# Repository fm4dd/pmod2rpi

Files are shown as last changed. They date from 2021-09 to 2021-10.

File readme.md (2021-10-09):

## PMOD2RPI

### Description

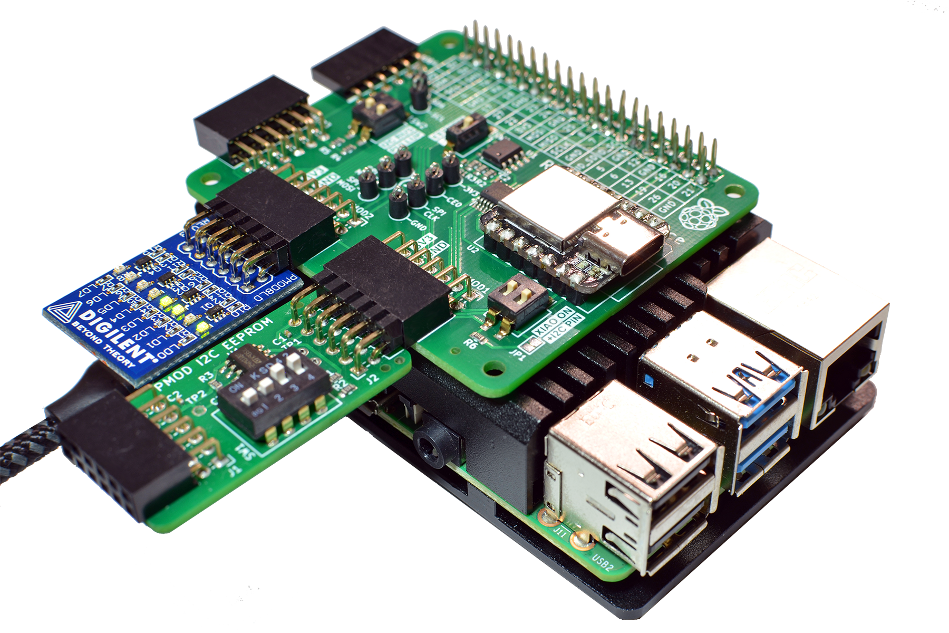
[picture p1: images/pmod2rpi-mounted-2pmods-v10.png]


PMOD2RPI is a PMOD-compatible Interface Board for the Raspberry Pi B-type GPIO connector. It provides a total of four PMOD connectors to run PMOD-compatible modules on the Raspberry Pi.  This board is compatible to PMOD interface standard v1.3.1 by Digilent Inc. The PMOD (peripheral module interface) standard enables simple plug-in connectivity between FPGA or microcontroller development boards, and a range of input/output modules.

This design is registered under the OSHWA Open Source Hardware Self-Certification:  


 While all connectors provide digital IO, they also double as serial bus connectors for I2C and SPI modules. To aid troubleshooting, a set of Keystone miniature testpins can be fitted to create access for oscilloscope and DMM monitoring. A Seeeduino XIAO footprint has been added to additionally drive two of the four PMOD's, or to communicate with the RPi. The XIAO is optional, and can operate with the board "standalone" if needed.

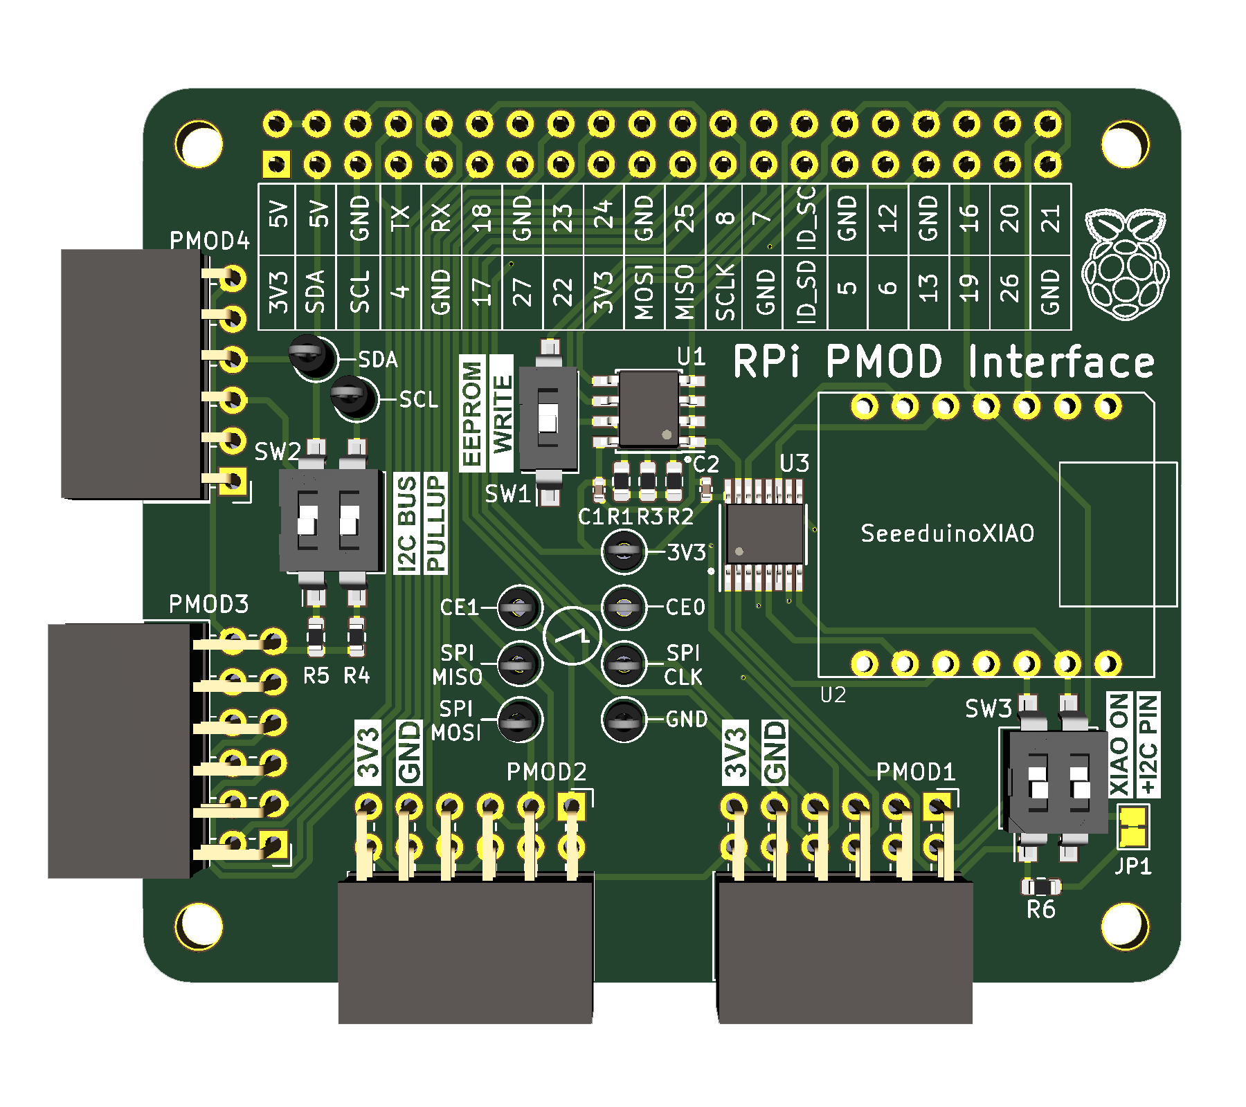
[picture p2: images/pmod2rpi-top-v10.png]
 

#### I2C /SPI signal switching on PMOD1

The PMOD interface standard v1.3.1 added a new extended I2C connector type 6A, which runs the I2C bus signals over the same pins 3/4 that are already used for SPI. In order to allow both bus types to be used on a single connector, switch SW3 allows to swap the I2C signals between pins 3/4 and 9/10 on PMOD1.

See also http://fpga.fm4dd.com/

### Schematic

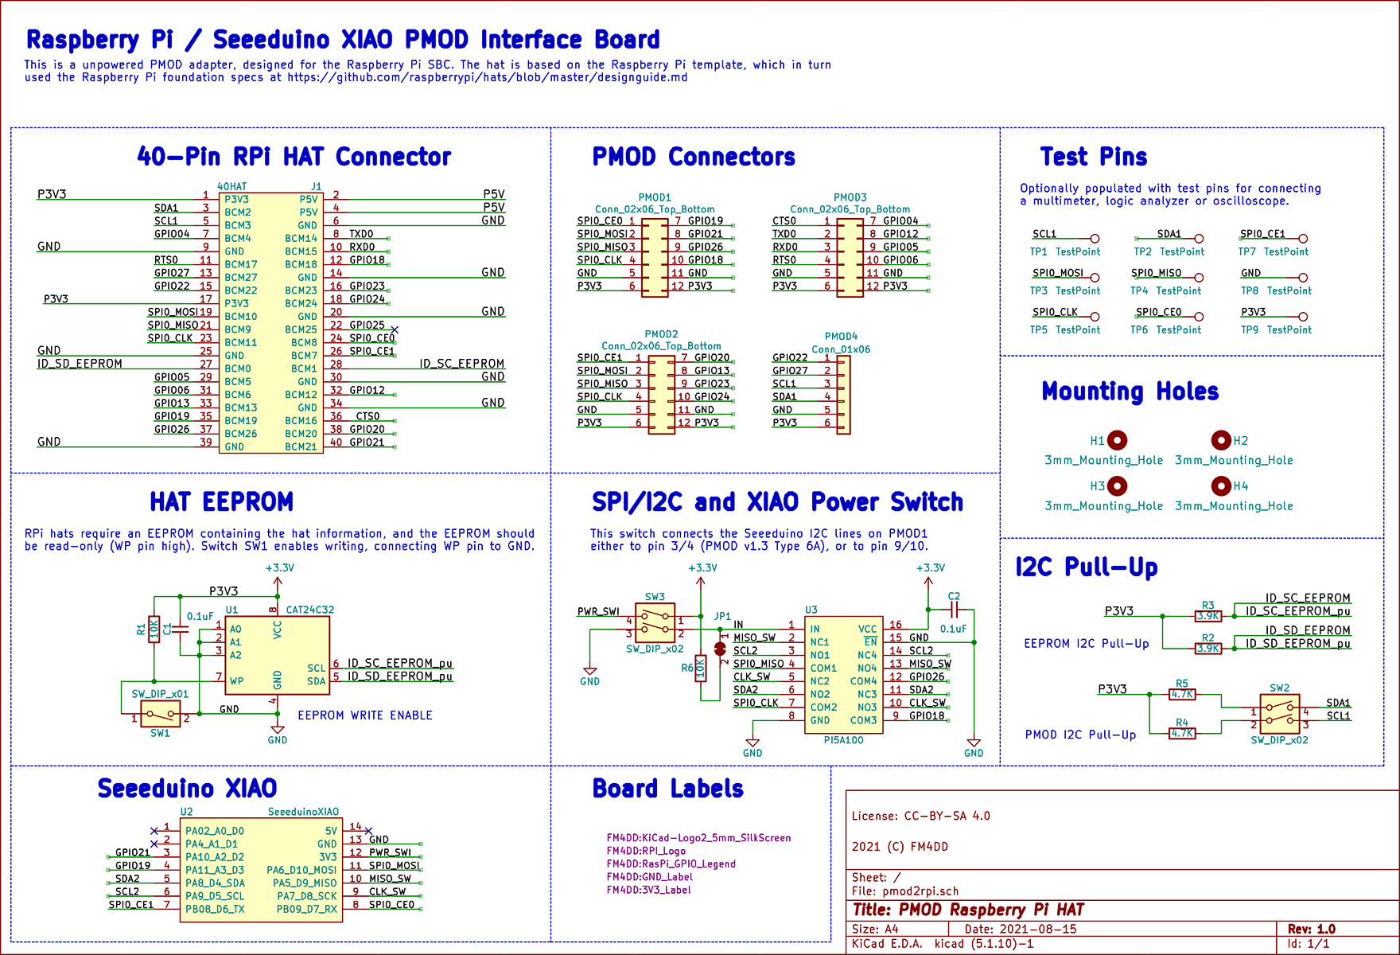
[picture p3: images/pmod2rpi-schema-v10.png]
I2C24IO PMOD Schematics


### Hardware Versions

| Version | Gerber | Schema |
|---|---|---|
| 1.0 |[20210821-pmod2rpi-gerber-v10.zip](release/v10/20210821-pmod2rpi-gerber-v10.zip) | [20210821-pmod2rpi-schema-v10.pdf](release/v10/20210821-pmod2rpi-schema-v10.pdf) |

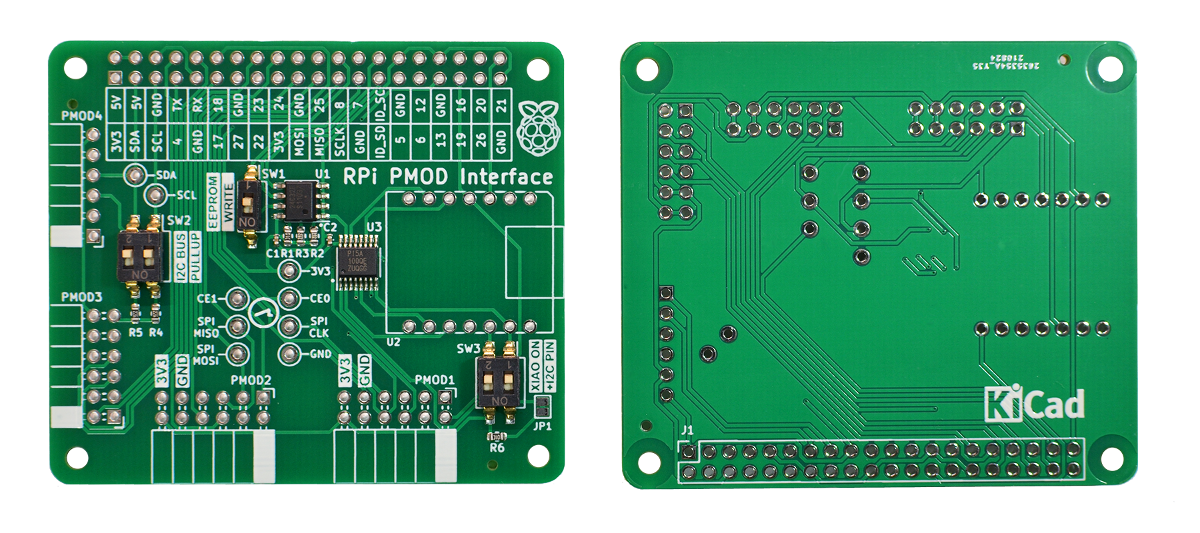
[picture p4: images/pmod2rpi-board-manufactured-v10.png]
 

### Pin Assignments

Pin assigments are listed in the separate [pmod2rpi-pinout.md](pmod2rpi-pinout.md) file.
Below are simplified schematics for the XIAO MCU-specific connectivity.

#### XIAO - PMOD1:

A multi-purpose double-row connector that can used as GPIO Type-1 and Type-1A, SPI Type-2 and Type-2A, or I2C Type-6 or Type-6A, depending on the pin configuration of the XIAO.
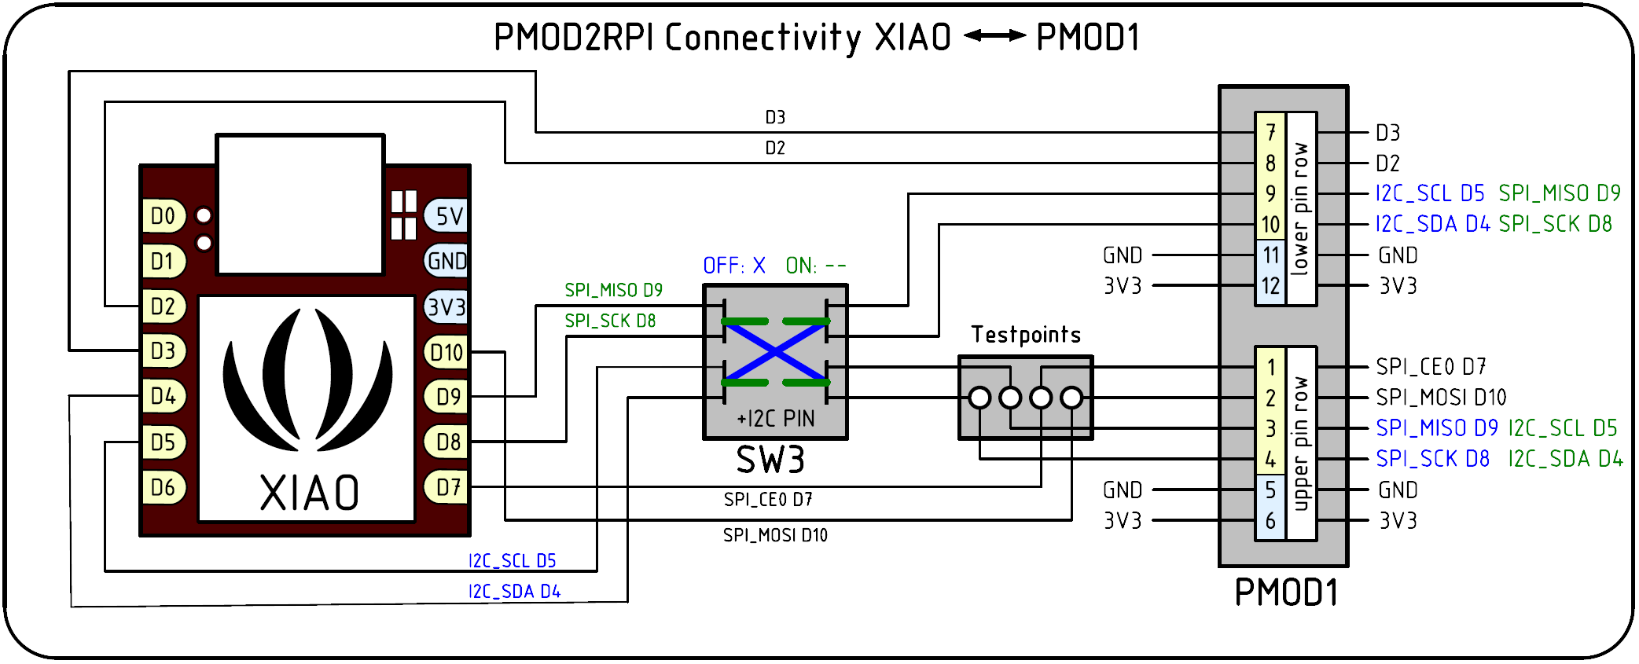
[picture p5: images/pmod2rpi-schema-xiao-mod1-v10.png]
I2C24IO PMOD Schematics

#### XIAO - PMOD2:

A double-row connector that can use only the upper row for GPIO Type-1, SPI Type-2, or I2C Type-6 configurations. The lower pins are connected to the Raspberry Pi only.
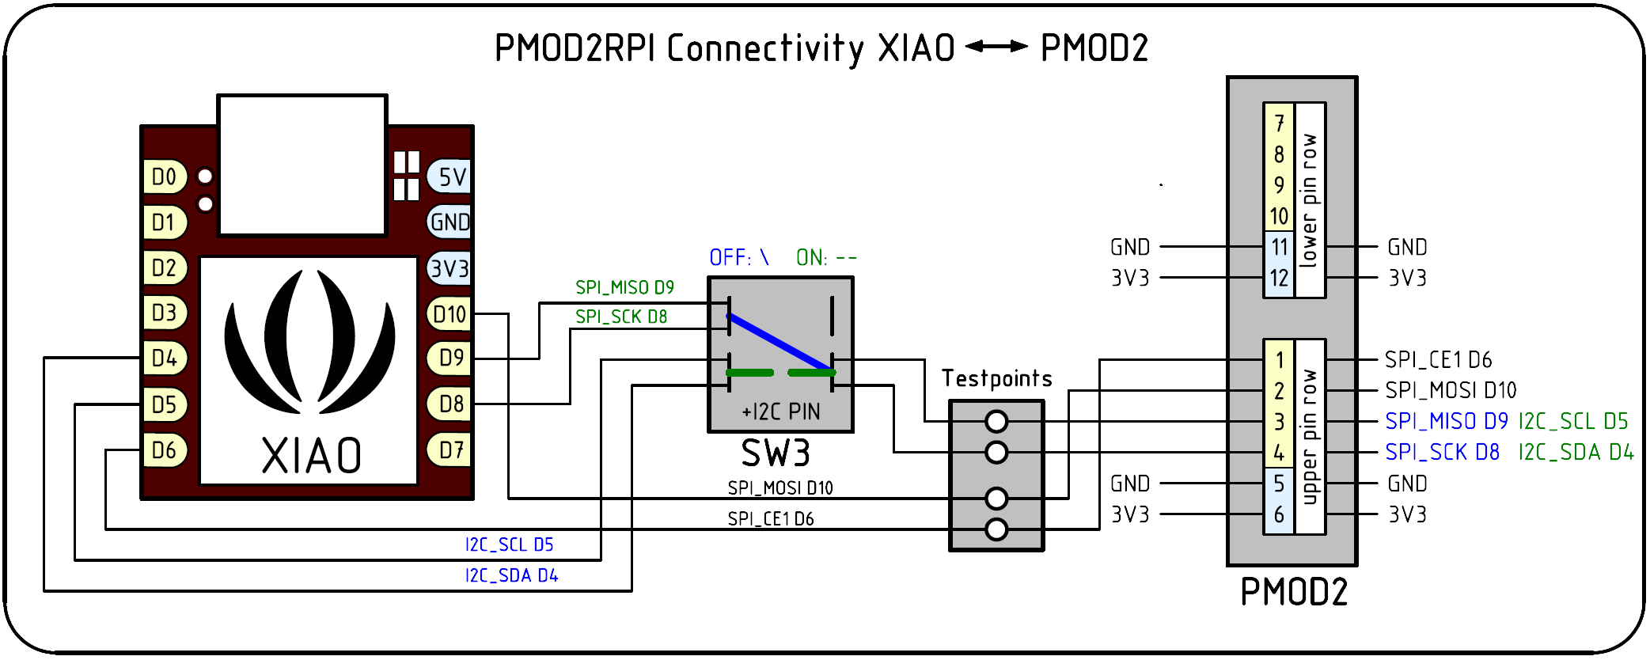
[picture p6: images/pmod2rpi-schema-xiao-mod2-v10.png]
I2C24IO PMOD Schematics

#### XIAO - Raspberry Pi:

A set of XIAO pins are shared with the Raspberry Pi that can be used to establish GPIO and SPI connections. With bitbanging, I2C is also possible for data exchange between the Pi and the XIAO.
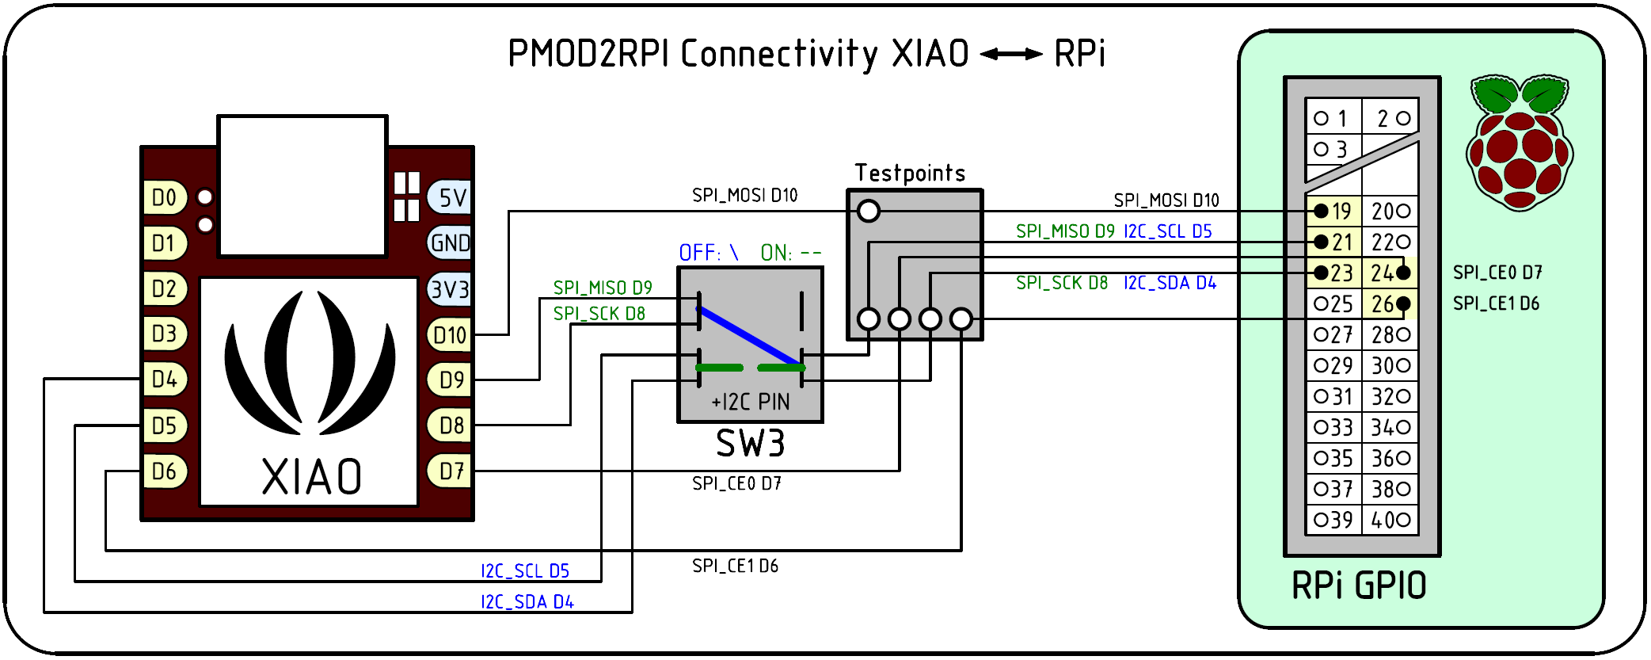
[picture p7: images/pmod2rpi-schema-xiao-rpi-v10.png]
I2C24IO PMOD Schematics


### Example Code

| Platform | Folder | Description |
|---|---|---|
|Raspberry Pi |[pi-gpiotest](examples/pi-gpiotest) | simple GPIO test program for digital IO PMODs, such as Digilent's PMOD8LD |
|Raspberry Pi |[pi-tca6424a](https://github.com/fm4dd/pmod-i2c24io/tree/master/examples/pi-tca6424a) | I2C module driver 'C' program to control the I2C expander module PMOD-I2C24IO connected to PMOD4 |
|Arduino |[xiao-digital-io](examples/xiao-digital-io) | Tests digital IO using the Digilent 8-Led PMOD 8LD connected to PMOD1 |
|Arduino |[xiao-pmod1-24iodemo](https://github.com/fm4dd/pmod-i2c24io/tree/master/examples/xiao-pmod1-24iodemo) | Creates a lightshow demo by rotating binary patterns over the 24 IO pins, lighting up connected LEDs |

I2C24IO PMOD demos are stored within the PMOD's repo located at [https://github.com/fm4dd/pmod-i2c24io](https://github.com/fm4dd/pmod-i2c24io).

### Board Pictures
I2C24IO PMOD connected to the RPi PMOD Interface board connector PMOD1, running the "xiao-pmod1-i2c24io" example program on the Seeeduino XIAO (Cortex M0) in "standalone" mode:
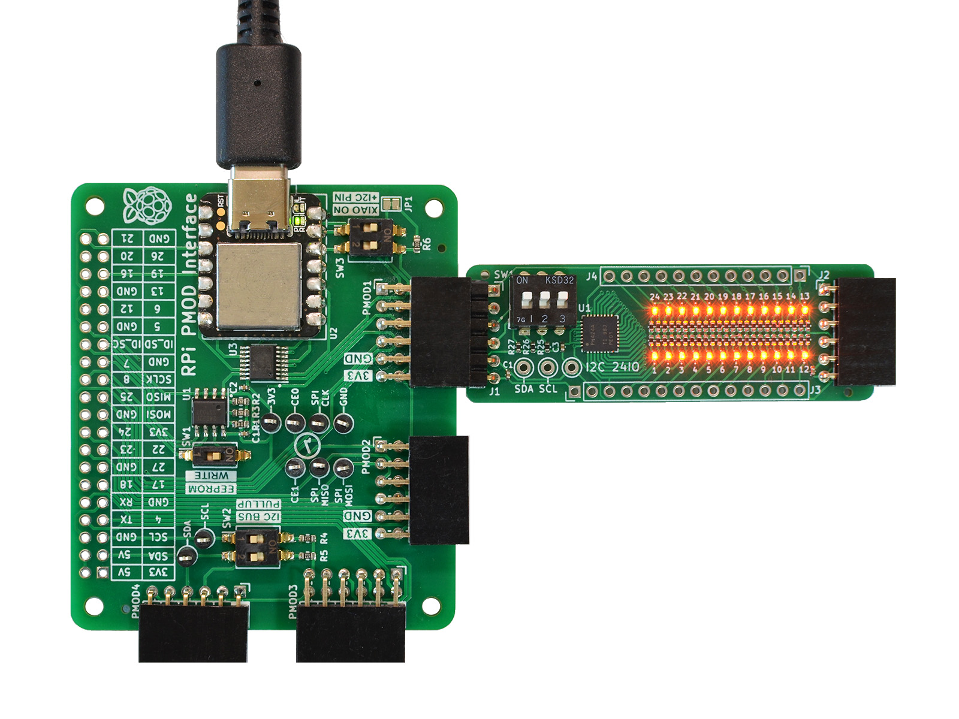
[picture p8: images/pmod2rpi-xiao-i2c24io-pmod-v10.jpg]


Raspberry Pi I2C signal measurements on the PMOD2RPI board:
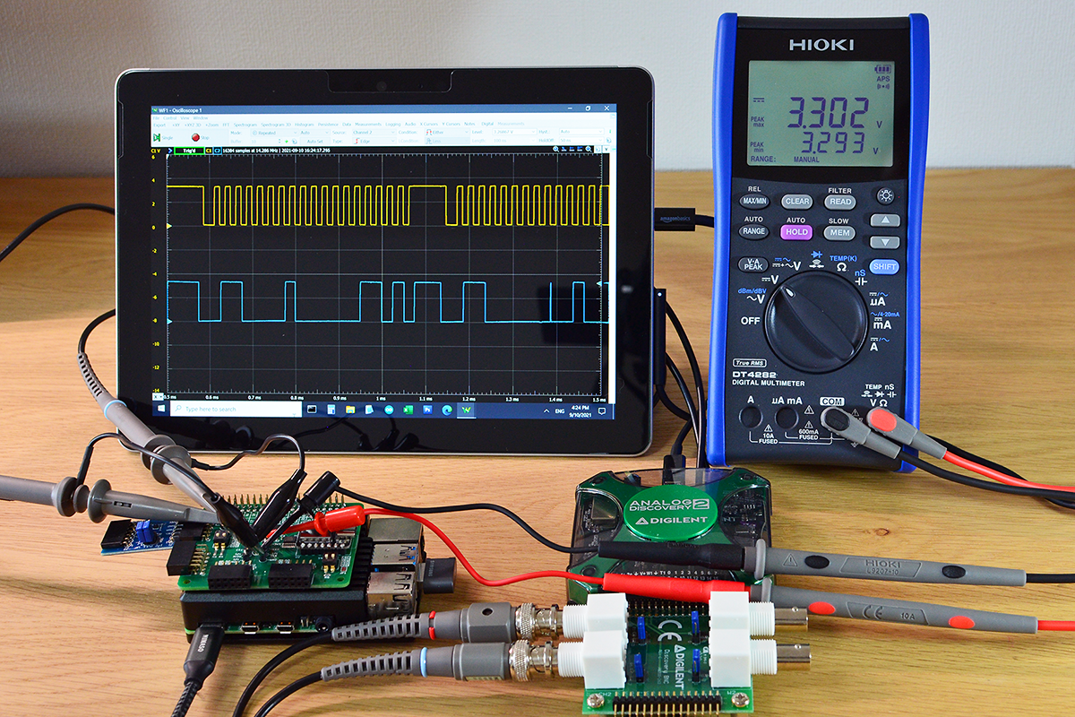
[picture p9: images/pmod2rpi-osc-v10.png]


Raspberry Pi operating the I2C24IO-PMOD module connected to PMOD4 on the PMOD2RPI board:
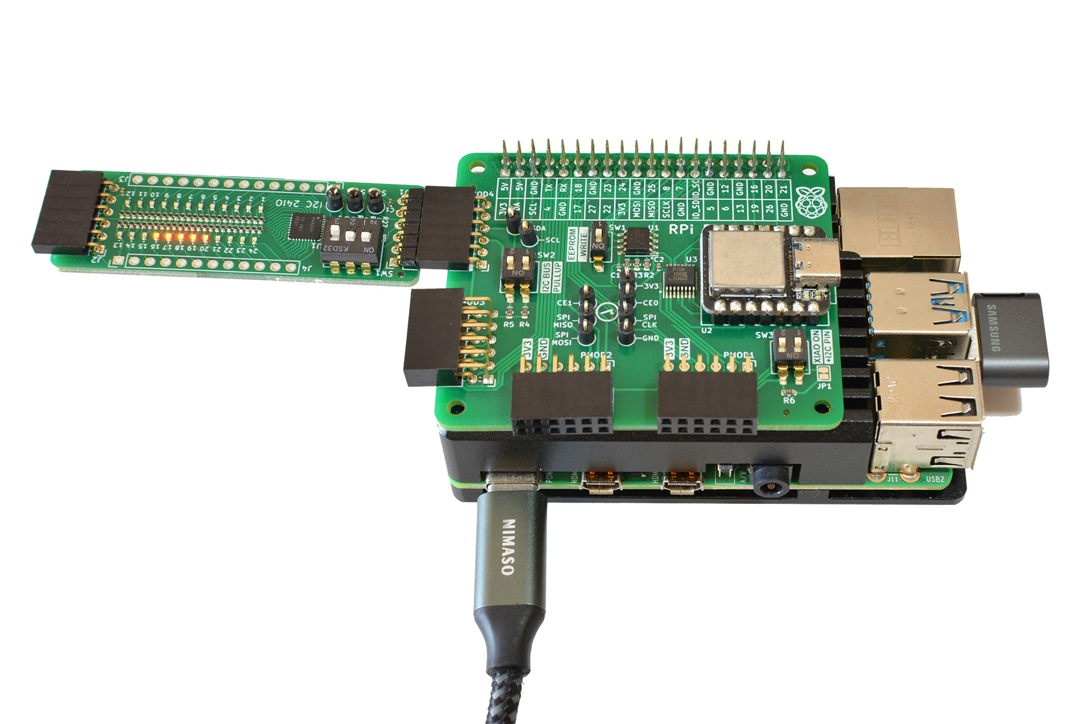
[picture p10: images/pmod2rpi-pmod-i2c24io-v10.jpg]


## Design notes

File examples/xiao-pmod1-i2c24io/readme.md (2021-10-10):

## XIAO-PMOD1-I2C24IO

Arduino Sketch for designs based on the I2C 24-bit digital expander IC Texas Instruments TCA6424A.
Implemented and tested on a PMOD2RPI interface board with a Seeeduino XIAO (Cortex M0+) and a I2C24IO PMOD module. 

### Usage

Running the sketch will output the following to the serial monitor:

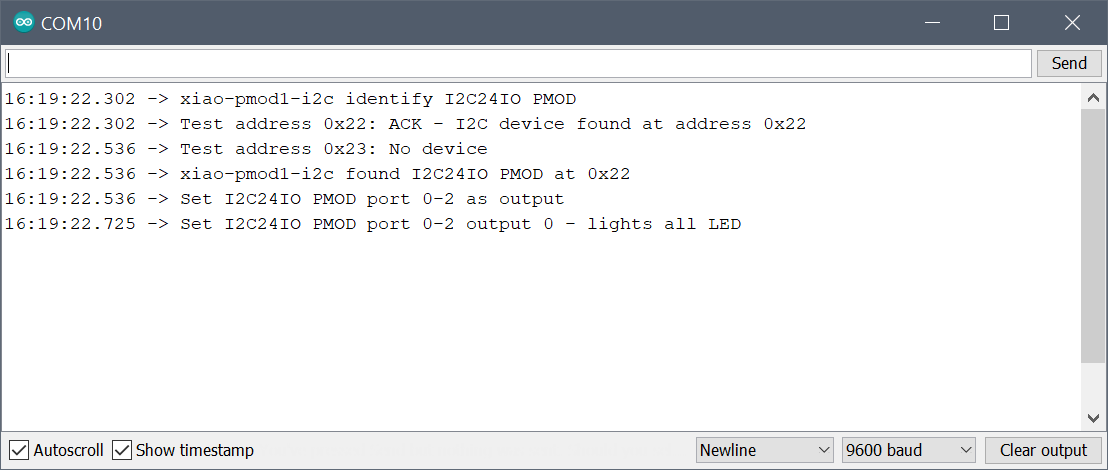
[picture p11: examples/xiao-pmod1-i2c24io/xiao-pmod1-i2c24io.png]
Sketch output to serial monitor


PMOD2RPI interface board with a Seeeduino XIAO (Cortex M0+) and a I2C24IO PMOD module:



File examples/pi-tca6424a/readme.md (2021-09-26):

## Pi-TCA6424A

Linux 'C' Control Code for designs based on the I2C 24-bit digital expander IC Texas Instruments TCA6424A.
Implemented and tested on a Raspberry Pi, using the PMOD2RPI interface board and a I2C24IO PMOD module. 

### Prerequisites

```
pi@pi-ms05:~ $ sudo apt install libi2c-dev libgpiod-dev
```

### Compilation

```
pi@pi-ms05:~/pmod-i2c24io/examples/pi-tca6424a $ make
gcc -O3 -Wall -g   -c -o i2c_tca6424a.o i2c_tca6424a.c
gcc -O3 -Wall -g   -c -o settca6424a.o settca6424a.c
gcc i2c_tca6424a.o settca6424a.o -o settca6424a -lgpiod
gcc -O3 -Wall -g   -c -o demotca6424a.o demotca6424a.c
gcc i2c_tca6424a.o demotca6424a.o -o demotca6424a -lgpiod
```

### Usage
```
pi@pi-ms05:~/pmod-i2c24io/examples/pi-tca6424a $ ./settca6424a
Usage: settca6424a [-b i2c-bus] [-d] [-i] -o [<24-bit output>, or all=0/1] [-r] [-v]

Command line parameters have the following format:
   -b   I2C bus to query, Example: -b /dev/i2c-1 (default)
   -d   dump the complete sensor register map content
   -i   print sensor information
   -o   24-bit binary output string, or all=0/1 to set all pins at once
        -o 111111110000000011111111 24 x 0/1 sets individual pins
        -o all=1 sets all pins 'on', -o all=0 sets all pins 'off'
   -r   reset sensor
   -h   display this message
   -v   enable debug output

Usage examples:
./settca6424a -b /dev/i2c-0 -i
./settca6424a -o all=1
./settca6424a -o 010101010101010101010101
```

### Examples

Enable all pins as output, and set the output level as '0':
```
pi@pi-ms05:~/pmod-i2c24io/examples/pi-tca6424a $ ./settca6424a -o all=0
```
Enable all pins as output, and set the output level as '1':
```
pi@pi-ms05:~/pmod-i2c24io/examples/pi-tca6424a $ ./settca6424a -o all=1
```
Enable all pins as output, and set individual pins according to the 24-bit pattern '111111110000000010101010':
```
pi@pi-ms05:~/pmod-i2c24io/examples/pi-tca6424a $ ./settca6424a -o 111111110000000010101010 -v
Debug: ts=[1632130627] date=Mon Sep 20 18:37:07 2021
Debug: Get pin gpio22: [direction 2]
Debug: Get pin gpio22: [act_state 1]
Debug: Set pin gpio22: [output '1']
Debug: I2C bus device: [/dev/i2c-1]
Debug: Sensor address: [0x22]
Debug: Got data @addr: [0x22]
Debug: Setting all ports as output complete
Debug: port0 data str: [11111111] hex [0xFF]
Debug: port1 data str: [00000000] hex [0x00]
Debug: port2 data str: [10101010] hex [0xAA]
Debug: Setting pin output as [111111110000000010101010] complete
```
Small one-liner to set pins as output, and alternate the pins output level:
``` 
pi@pi-ms05:~/pmod-i2c24io/examples/pi-tca6424a $ while true; do ./settca6424a -o 101010101010101010101010; \
> sleep 0.5; ./settca6424a -o 010101010101010101010101; sleep 0.5; done
```
Set a specific pin value, and dump the TCA6424A register values:
```
pi@pi-ms05:~/pmod-i2c24io/examples/pi-tca6424a $ ./settca6424a -o 111111110000000010101010
pi@pi-ms05:~/pmod-i2c24io/examples/pi-tca6424a $ ./settca6424a -d
------------------------------------------------------
Texas Instruments TCA6424A register dump:
------------------------------------------------------
 reg    0  1  2  3  4  5  6  7  8  9  A  B  C  D  E  F
------------------------------------------------------
[0x00] FF 00 AA -- FF 00 AA -- 00 00 00 -- 00 00 00 --
```

### Demo

```
pi@pi-ms05:~/pmod-i2c24io/examples/pi-tca6424a $ ./demotca6424a
```

demotca6424 is demonstration program for designs based on the I2C 24-bit digital expander IC Texas Instruments TCA6424A.
Implemented and tested on a Raspberry Pi 4 with a PMOD2RPI interface board, having the I2C24IO PMOD module on the PMOD4 connector.

### Usage

```
pi@pi-ms05:~/pmod-i2c24io/examples/pi-tca6424a $ ./demotca6424a -h
Usage: demotca6424a [-a addr] [-b i2c-bus] [-v]

Command line parameters have the following format:
   -a   module I2C bus address in hex, Example: -a 0x22 (default)
   -b   I2C bus to query, Example: -b /dev/i2c-1 (default)
   -h   display this message
   -v   enable debug output

Usage examples:
./demotca6424a -a 0x23 -b /dev/i2c-0
./demotca6424a -v
```

Running the sketch will output various LED patterns that indicate the IO signal status:

1. ON/OFF for all pins on the module
2. Moving a single bit through each of the 24 pins
3. Moving 3 bits, one for each of the 3 output ports
4. Increment pins from 0 until all port pins are ON/OFF
5. Moving 6 bits, two for each of the 3 output ports
6. Alternate the level for neighporing pins ON/OFF

This program executes in a permanent loop, terminate the program with 'CTL-C'.

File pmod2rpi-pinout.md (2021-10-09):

## RPi Pin Assignments

### Raspberry Pi 40-Pin Connector GPIO assignment list

| RPi Pin-# | RPi Pin Name | PMOD#-Pin# | RPi Pin-# | RPi Pin Name | PMOD#-Pin# |
|---|---|---|---|---|---|
| 1 | 3V3 | All (Pin-6) | 2 | 5V | - |
| 3 | GPIO02 | PMOD4-4 | 4 | 5V | - |
| 5 | GPIO03 | PMOD4-3 | 6 | GND | All (GND Pin-5)|
| 7 | GPIO04 | PMOD3-7 | 8 | GPIO14 | PMOD2-1 |
| 9 | GND | All (GND Pin-5) | 10 | GPIO15 | PMOD3-3 |
| 11 | GPIO17 | PMOD3-4 | 12 | GPIO18 | PMOD1-10 |
| 13 | GPIO27 | PMOD4-2 | 14 | GND | All (GND Pin-5)|
| 15 | GPIO22 | PMOD4-1 | 16 | GPIO23 | PMOD2-9 |
| 17 | 3V3 | All (Pin-6) | 18 | GPIO24 | PMOD2-10 |
| 19 | GPIO10 | PMOD1-2, PMOD2-2| 20 | GND | All (GND Pin-5)|
| 21 | GPIO09 | PMOD1-3, PMOD2-3| 22 | GPIO25 | PMOD2-10 |
| 23 | GPIO11 | PMOD1-4, PMOD2-4| 24 | GPIO08 | PMOD1-1 |
| 25 | GND | All (GND Pin-5) | 26 | GPIO07 | PMOD2-1 |
| 27 | ID_SD_EEPROM | U1 EEPROM SDA | 28 | ID_SC_EEPROM | U1 EEPROM SCL  |
| 29 | GPIO05 | PMOD3-9 | 30 | GND | All (GND Pin-5)|
| 31 | GPIO06 | PMOD3-10 | 32 | GPIO12 | PMOD3-8 |
| 33 | GPIO13 | PMOD2-8 | 34 | GND | All (GND Pin-5)|
| 35 | GPIO19 | PMOD1-7 | 36 | GPIO16 | PMOD3-1 |
| 37 | GPIO26 | PMOD1-9 | 38 | GPIO20 | PMOD2-7 |
| 39 | GND | All (GND Pin-5) | 40 | GPIO21 | PMOD1-8 |

## PMOD pinout

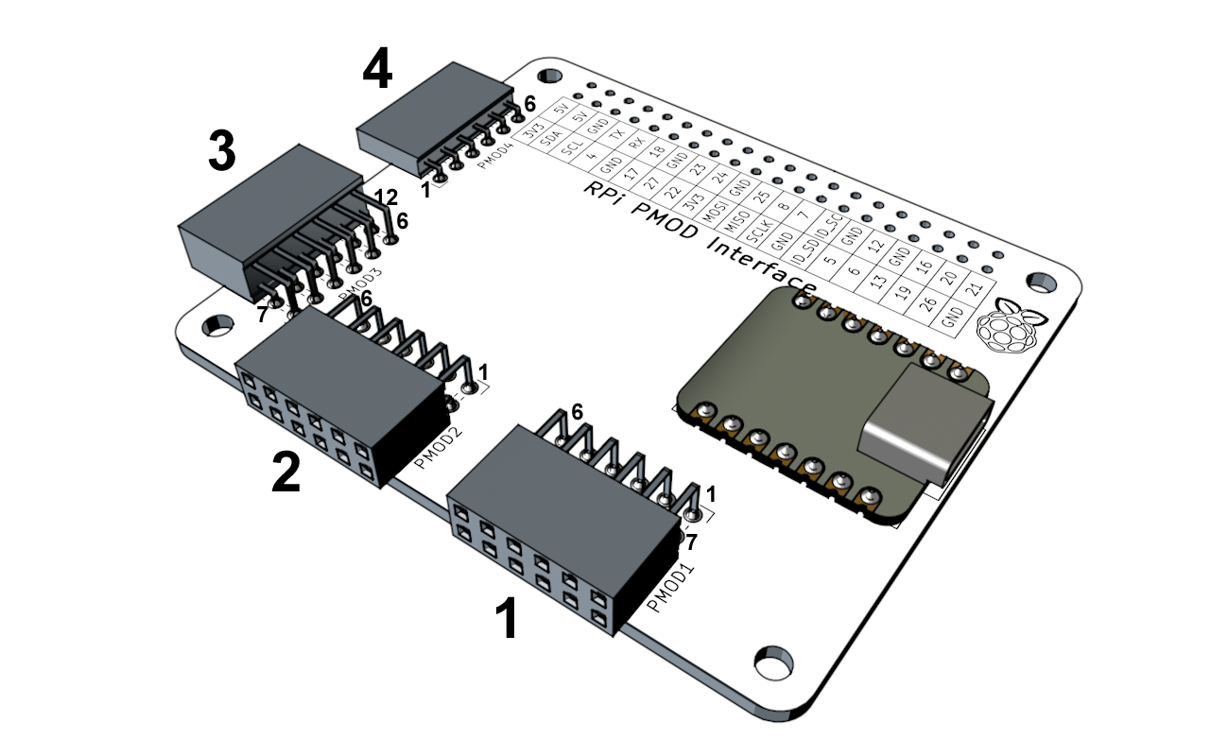
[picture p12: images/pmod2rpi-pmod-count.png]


### PMOD1 pin assignment list

#### Top Row

| PMOD Pin# | RPi Pin Name | RPi Alternate  | RPi Pin-# | XIAO Pin Name | XIAO-Pin# |
|---|---|---|---|---|---|
| 1 | GPIO08 | SPI0_CE0 | 24 | D7 | 8 |
| 2 | GPIO10 | SPI0_MOSI | 19 | D10 | 11 |
| 3 | GPIO09 | SPI0_MISO | 21 | D9 (D5) | 10 |
| 4 | GPIO11 | SPI0_CLK | 23 | D8 (D4) | 9 |
| 5 | GND | GND | 6,9,14... | GND | 13 |
| 6 | 3V3 | - | 1,17 | 3V3 | 12 |

#### Bottom Row

| PMOD Pin# | RPi Pin Name | RPi Alternate  | RPi Pin-# | XIAO Pin Name | XIAO-Pin# |
|---|---|---|---|---|---|
| 7 | GPIO19 | - | 35 | D3 | 4 |
| 8 | GPIO21 | - | 40 | D2 | 3 |
| 9 | GPIO26 | - | 37 | D5 (D9) | 6 (10) |
| 10 | GPIO18 | - | 12 | D4 (D8) | 5 (9) |
| 11 | GND | - | 6,9,14... | GND | 13 |
| 12 | 3V3 | - | 1,17 | 3V3 | 12 |

XIAO pins with alternate pins in () are controlled by the "+I2C Pin" DIP switch setting of SW3.

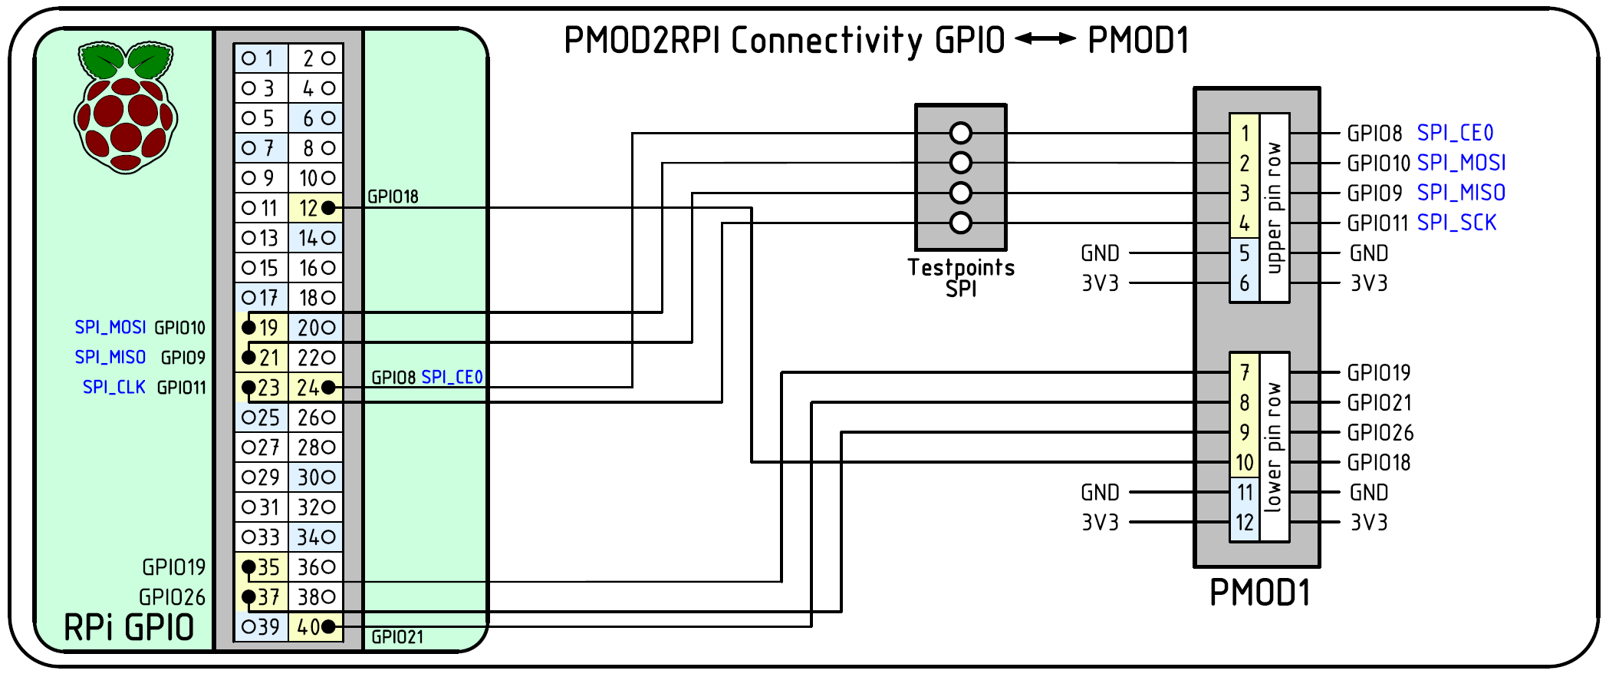
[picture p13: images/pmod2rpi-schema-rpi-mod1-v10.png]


### PMOD2 pin assignment list

#### Top Row

| PMOD Pin# | RPi Pin Name | RPi Alternate  | RPi Pin-# | XIAO Pin Name | XIAO-Pin# |
|---|---|---|---|---|---|
| 1 | GPIO07 | SPI0_CE1 | 26 | D7 | 8 |
| 2 | GPIO10 | SPI0_MOSI | 19 | D10 | 11 |
| 3 | GPIO09 | SPI0_MISO | 21 | D9 (D5) | 10 |
| 4 | GPIO11 | SPI0_CLK | 23 | D8 (D4) | 9 |
| 5 | GND | GND | 6,9,14... | GND | 13 |
| 6 | 3V3 | - | 1,17 | 3V3 | 12 |

XIAO pins with alternate pins in () are controlled by the "+I2C Pin" DIP switch setting of SW3.

#### Bottom Row

| PMOD Pin# | RPi Pin Name | RPi Alternate  | RPi Pin-# |
|---|---|---|---|
| 7 | GPIO20 | - | 38 |
| 8 | GPIO13 | - | 33 |
| 9 | GPIO23 | - | 16 |
| 10 | GPIO24 | - | 18 |
| 11 | GND | - | 6,9,14... |
| 12 | 3V3 | - | 1,17 |

The bottom row is not connected to any XIAO pins.

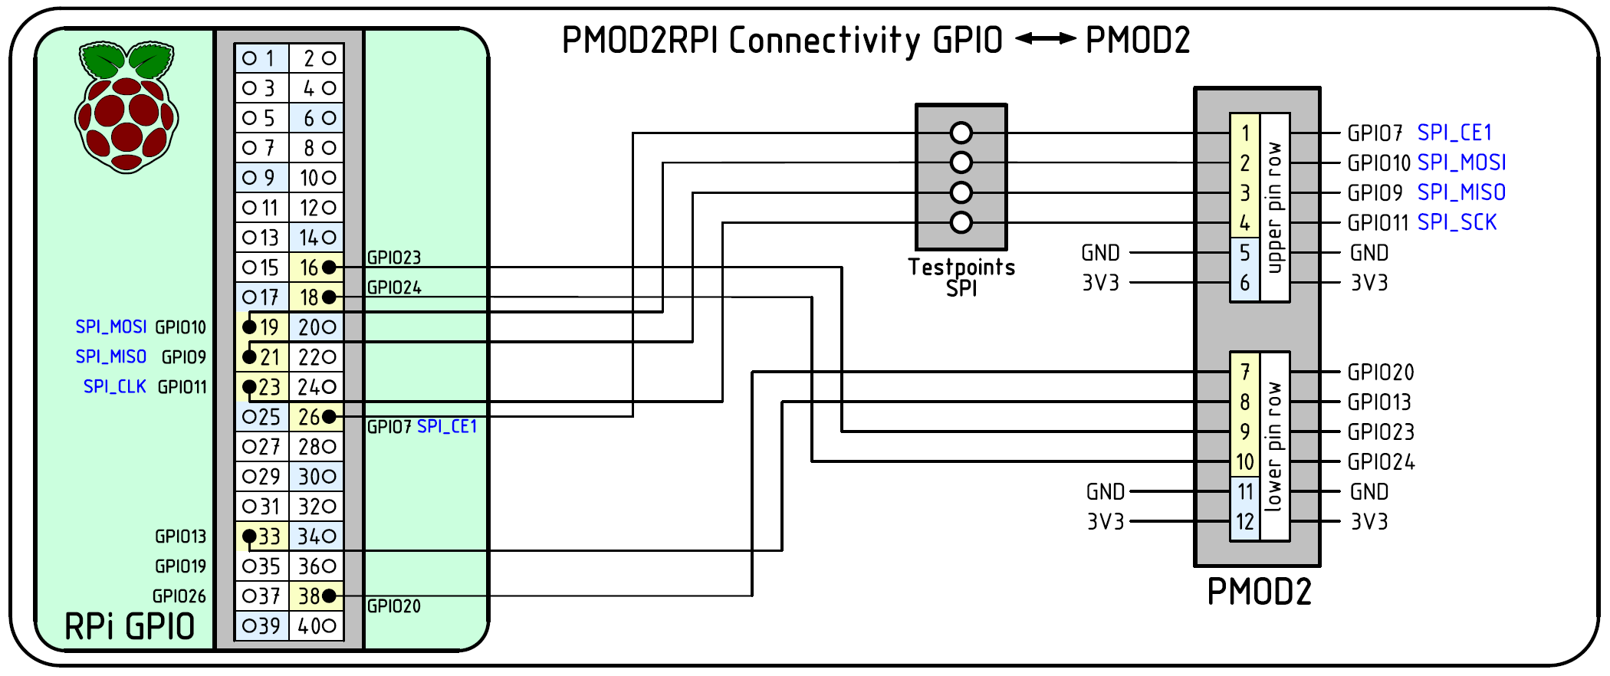
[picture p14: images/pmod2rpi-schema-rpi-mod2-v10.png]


### PMOD3 pin assignment list

#### Top Row

| PMOD Pin# | RPi Pin Name | RPi Alternate  | RPi Pin-# |
|---|---|---|---|
| 1 | GPIO16 | CTS | 36 |
| 2 | GPIO14 | TXD | 8 |
| 3 | GPIO15 | RXD | 10 |
| 4 | GPIO17 | RTS | 11 |
| 5 | GND | GND | 6,9,14... |
| 6 | 3V3 | - | 1,17 |

#### Bottom Row

| PMOD Pin# | RPi Pin Name | RPi Alternate  | RPi Pin-# |
|---|---|---|---|
| 7 | GPIO04 | - | 7 |
| 8 | GPIO12 | - | 32 |
| 9 | GPIO05 | - | 29 |
| 10 | GPIO06 | - | 31 |
| 11 | GND | - | 6,9,14... |
| 12 | 3V3 | - | 1,17 |

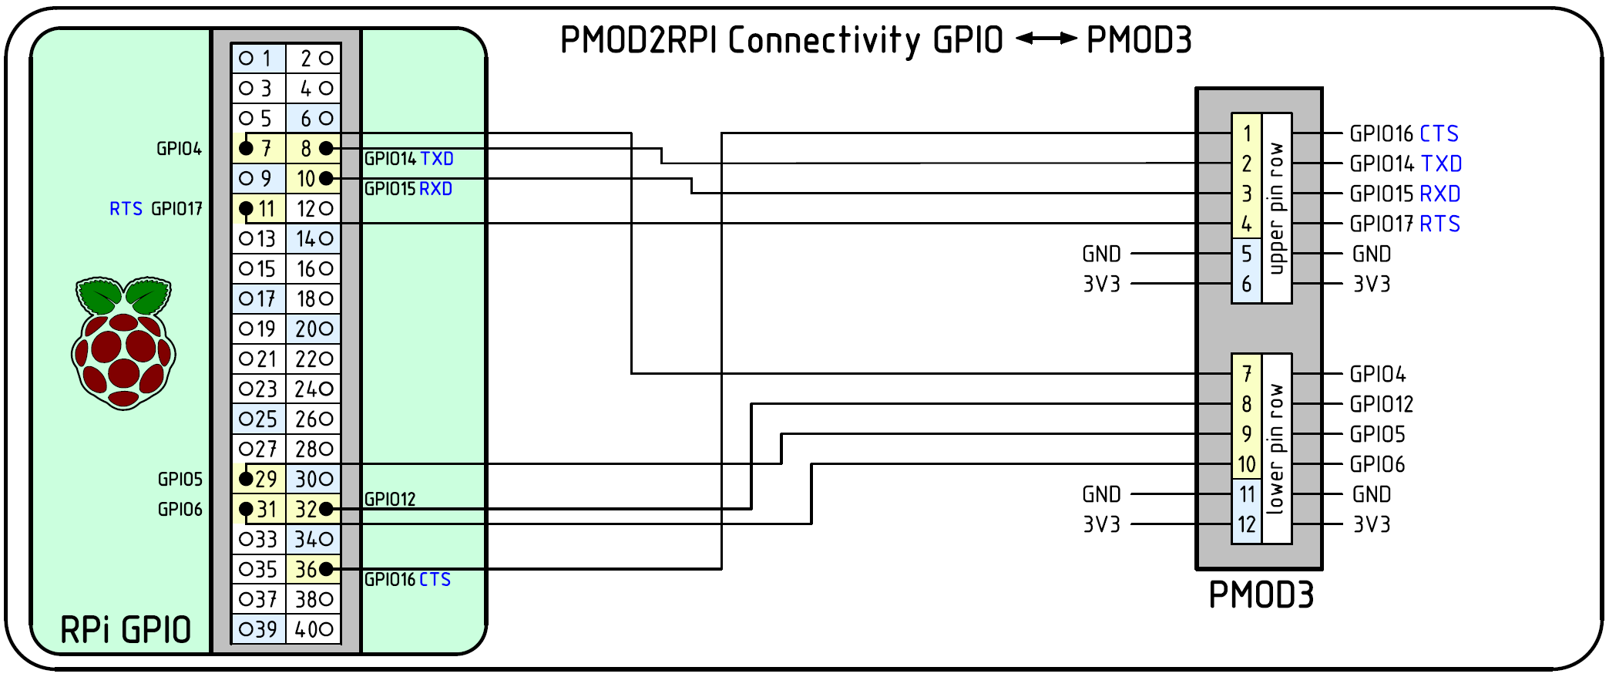
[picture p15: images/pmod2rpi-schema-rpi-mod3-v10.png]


### PMOD4 pin assignment list

#### Pin Row

| PMOD Pin# | RPi Pin Name | RPi Alternate  | RPi Pin-# |
|---|---|---|---|
| 1 | GPIO22 | - | 15 |
| 2 | GPIO27 | - | 13 |
| 3 | GPIO03 | I2C_SCL | 5 |
| 4 | GPIO02 | I2C_SDA | 3 |
| 5 | GND | GND | 6,9,14... |
| 6 | 3V3 | - | 1,17 |

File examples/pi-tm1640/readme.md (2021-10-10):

## Pi-TM1640

Linux 'C' Control Code for designs based on the Titan Micro LED Driver IC TM1640.
Implemented and tested on a Raspberry Pi, using the PMOD2RPI interface board and a PMOD-7SEG9 module. 

The code defaults the clock/data pins to GPIO 18/26 located on PMOD1 lower row.
Calling the control program with -c/-d arguments sets the pins to other values.
To operate the PMOD-7SEG9 module on PMOD2 lower row, use ./settm1640 -c 24 -d 23.

### Prerequisites

```
pi@pi-ms05:~ $ sudo apt install libgpiod-dev
```

### Compilation

```
pi@pi-ms05:~/pmod2rpi/pi-tm1640 $ make
gcc -O3 -Wall -g   -c -o tm1640.o tm1640.c
gcc -O3 -Wall -g   -c -o settm1640.o settm1640.c
gcc tm1640.o settm1640.o -o settm1640 -lgpiod
```

### Usage
```
pi@pi-ms05:~/pmod2rpi/pi-tm1640 $ ./settm1640
Usage: settm1640 [-c <clockpin>] [-d <datapin>] -b <brightness>
       settm1640 [-c <clockpin>] [-d <datapin>] [-i] -o <display-digits> [-a <l|r>]
       settm1640 [-c <clockpin>] [-d <datapin>] -e
       settm1640 [-c <clockpin>] [-d <datapin>] -o

Command line parameters have the following format:
   -a   left/right alignment either 'l' or 'r' (default)
   -b   enable display with LED brightness 0..7
        example: -b 5
   -c   clock pin GPIO number
   -d   data pin GPIO number
   -e   empty (clear) the display
   -i   vertical inverted (together with -w)
   -o   display off switch
   -w   1..9-digit output string to display
        example: -o 12345678
   -h   display this message
   -v   enable debug output

Usage examples:
./settm1640 -c 18 -d 26 -b 2
./settm1640 -c 18 -d 26 -e
./settm1640 -c 18 -d 26 -o
./settm1640 -c 18 -d 26 -w 876543210
```

### Examples

Enable the 7-Seg display connected to PMOD2RPI PMOD1 (lower row), with verbose on:
```
pi@pi-ms05:~/pmod2rpi/pi-tm1640 $ ./settm1640 -v -b 4
Debug: arg -b, value 4
Debug: ts=[1633842468] date=Sun Oct 10 14:07:48 2021
Debug: tm1640_init(c=18, d=26)
Debug: tm1640_sendCmd(0x8C)
  Debug: tm1640_sendRaw(0x8C) 10001100 ...complete
...Cmd done
Debug: tm1640_on(4) complete
```

Write the string "9.87654" to the 7-Seg display on PMOD2RPI PMOD1 (lower row), with verbose on:
```
pi@pi-ms05:~/pmod2rpi/pi-tm1640 $ ./settm1640 -v -w 9.87654
Debug: arg -w, value 9.87654
Debug: ts=[1633842358] date=Sun Oct 10 14:05:58 2021
Debug: tm1640_init(c=18, d=26)
Debug: tm1640_write(s=9.87654 l=7 i=0):
  Debug: char 9 = 01101111
  Debug: char . = 10000000
  Debug: char 8 = 01111111
  Debug: char 7 = 00100111
  Debug: char 6 = 01111101
  Debug: char 5 = 01101101
  Debug: char 4 = 01100110
Debug: tm1640_sendCmd(0x44)
  Debug: tm1640_sendRaw(0x44) 01000100 ...complete
...Cmd done
  Debug: tm1640_sendRaw(0xC0) 11000000 ...complete
  Debug: tm1640_sendRaw(0xEF) 11101111 ...complete
  Debug: tm1640_sendRaw(0x7F) 01111111 ...complete
  Debug: tm1640_sendRaw(0x27) 00100111 ...complete
  Debug: tm1640_sendRaw(0x7D) 01111101 ...complete
  Debug: tm1640_sendRaw(0x6D) 01101101 ...complete
  Debug: tm1640_sendRaw(0x66) 01100110 ...complete
  Debug: tm1640_sendRaw(0x00) 00000000 ...complete
  Debug: tm1640_sendRaw(0x00) 00000000 ...complete
  Debug: tm1640_sendRaw(0x00) 00000000 ...complete
...write done
```

Write the same string "9.87654" with verbose on, but with the output vertically inverted:
```
pi@pi-ms05:~/pmod2rpi/pi-tm1640 $ ./settm1640 -v -w 9.87654 -i
Debug: arg -w, value 9.87654
Debug: arg -i
Debug: ts=[1633842391] date=Sun Oct 10 14:06:31 2021
Debug: tm1640_init(c=18, d=26)
Debug: tm1640_write(s=9.87654 l=7 i=1):
  Debug: invert 01100110 = 01110100
  Debug: char 4 = 01110100
  Debug: invert 01101101 = 01101101
  Debug: char 5 = 01101101
  Debug: invert 01111101 = 01101111
  Debug: char 6 = 01101111
  Debug: invert 00100111 = 00111100
  Debug: char 7 = 00111100
  Debug: invert 01111111 = 01111111
  Debug: char 8 = 01111111
  Debug: invert 10000000 = 10000000
  Debug: char . = 10000000
  Debug: invert 01101111 = 01111101
  Debug: char 9 = 01111101
Debug: tm1640_sendCmd(0x44)
  Debug: tm1640_sendRaw(0x44) 01000100 ...complete
...Cmd done
  Debug: tm1640_sendRaw(0xC0) 11000000 ...complete
  Debug: tm1640_sendRaw(0x74) 01110100 ...complete
  Debug: tm1640_sendRaw(0x6D) 01101101 ...complete
  Debug: tm1640_sendRaw(0x6F) 01101111 ...complete
  Debug: tm1640_sendRaw(0x3C) 00111100 ...complete
  Debug: tm1640_sendRaw(0xFF) 11111111 ...complete
  Debug: tm1640_sendRaw(0x7D) 01111101 ...complete
  Debug: tm1640_sendRaw(0x00) 00000000 ...complete
  Debug: tm1640_sendRaw(0x00) 00000000 ...complete
  Debug: tm1640_sendRaw(0x00) 00000000 ...complete
...write done
```

Using the -e argument clears the display (writing 'null' bytes):
``` 
pi@pi-ms05:~/pmod2rpi/pi-tm1640 $ ./settm1640 -v -e
Debug: arg -e
Debug: ts=[1633842773] date=Sun Oct 10 14:12:53 2021
Debug: tm1640_init(c=18, d=26)
  Debug: tm1640_sendRaw(0xC0) 11000000 ...complete
  Debug: tm1640_sendRaw(0x00) 00000000 ...complete
  Debug: tm1640_sendRaw(0x00) 00000000 ...complete
  Debug: tm1640_sendRaw(0x00) 00000000 ...complete
  Debug: tm1640_sendRaw(0x00) 00000000 ...complete
  Debug: tm1640_sendRaw(0x00) 00000000 ...complete
  Debug: tm1640_sendRaw(0x00) 00000000 ...complete
  Debug: tm1640_sendRaw(0x00) 00000000 ...complete
  Debug: tm1640_sendRaw(0x00) 00000000 ...complete
  Debug: tm1640_sendRaw(0x00) 00000000 ...complete
  Debug: tm1640_sendRaw(0x00) 00000000 ...complete
  Debug: tm1640_sendRaw(0x00) 00000000 ...complete
  Debug: tm1640_sendRaw(0x00) 00000000 ...complete
  Debug: tm1640_sendRaw(0x00) 00000000 ...complete
  Debug: tm1640_sendRaw(0x00) 00000000 ...complete
  Debug: tm1640_sendRaw(0x00) 00000000 ...complete
  Debug: tm1640_sendRaw(0x00) 00000000 ...complete
```

We can turn the display off with -o. This keeps the previous content, and a turn-on restores the output:
```
pi@pi-ms05:~/pmod2rpi/pi-tm1640 $ ./settm1640 -v -o
Debug: arg -o
Debug: ts=[1633842994] date=Sun Oct 10 14:16:34 2021
Debug: tm1640_init(c=18, d=26)
Debug: tm1640_sendCmd(0x80)
  Debug: tm1640_sendRaw(0x80) 10000000 ...complete
...Cmd done
Debug: tm1640_off() complete

pi@pi-ms05:~/pmod2rpi/pi-tm1640 $ ./settm1640 -v -b 4
Debug: arg -b, value 4
Debug: ts=[1633842997] date=Sun Oct 10 14:16:37 2021
Debug: tm1640_init(c=18, d=26)
Debug: tm1640_sendCmd(0x8C)
  Debug: tm1640_sendRaw(0x8C) 10001100 ...complete
...Cmd done
Debug: tm1640_on(4) complete
```

Multiple 7-Segment PMODs can be controlled in parallel by specifying the clock/data pins:
```
pi@pi-ms05:~/pmod2rpi/pi-tm1640 $ ./settm1640 -v -c 24 -d 23 -w "  12.34567"
Debug: arg -c, value 24
Debug: arg -d, value 23
Debug: arg -w, value   12.34567
Debug: ts=[1633843283] date=Sun Oct 10 14:21:23 2021
Debug: tm1640_init(c=24, d=23)
Debug: tm1640_write(s=  12.34567 l=10 i=0):
  Debug: char   = 00000000
  Debug: char   = 00000000
  Debug: char 1 = 00000110
  Debug: char 2 = 01011011
  Debug: char . = 10000000
  Debug: char 3 = 01001111
  Debug: char 4 = 01100110
  Debug: char 5 = 01101101
  Debug: char 6 = 01111101
  Debug: char 7 = 00100111
Debug: tm1640_sendCmd(0x44)
  Debug: tm1640_sendRaw(0x44) 01000100 ...complete
...Cmd done
  Debug: tm1640_sendRaw(0xC0) 11000000 ...complete
  Debug: tm1640_sendRaw(0x00) 00000000 ...complete
  Debug: tm1640_sendRaw(0x00) 00000000 ...complete
  Debug: tm1640_sendRaw(0x06) 00000110 ...complete
  Debug: tm1640_sendRaw(0xDB) 11011011 ...complete
  Debug: tm1640_sendRaw(0x4F) 01001111 ...complete
  Debug: tm1640_sendRaw(0x66) 01100110 ...complete
  Debug: tm1640_sendRaw(0x6D) 01101101 ...complete
  Debug: tm1640_sendRaw(0x7D) 01111101 ...complete
  Debug: tm1640_sendRaw(0x27) 00100111 ...complete
...write done
```

This example with 7seg9 PMODs connected to a Raspberry Pi via the PMOD2RPI interface board:
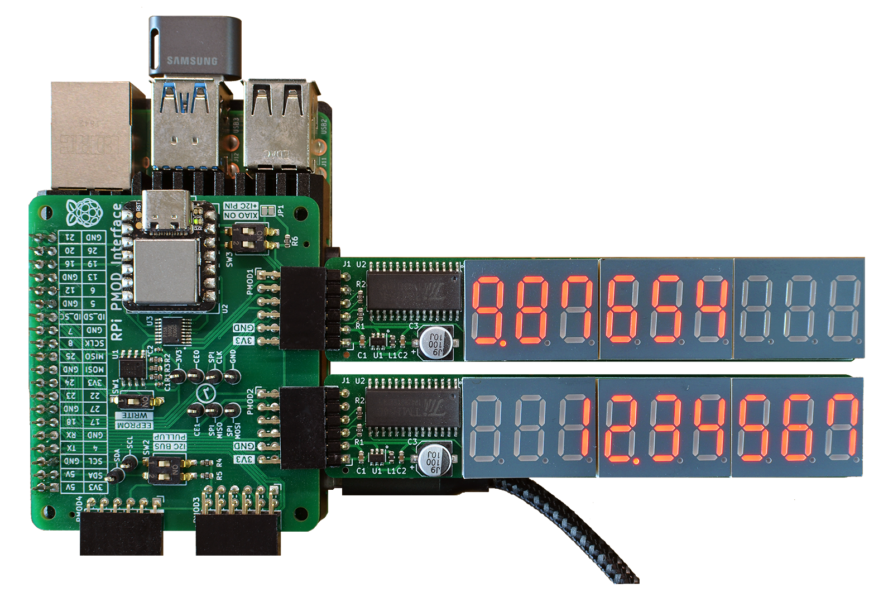
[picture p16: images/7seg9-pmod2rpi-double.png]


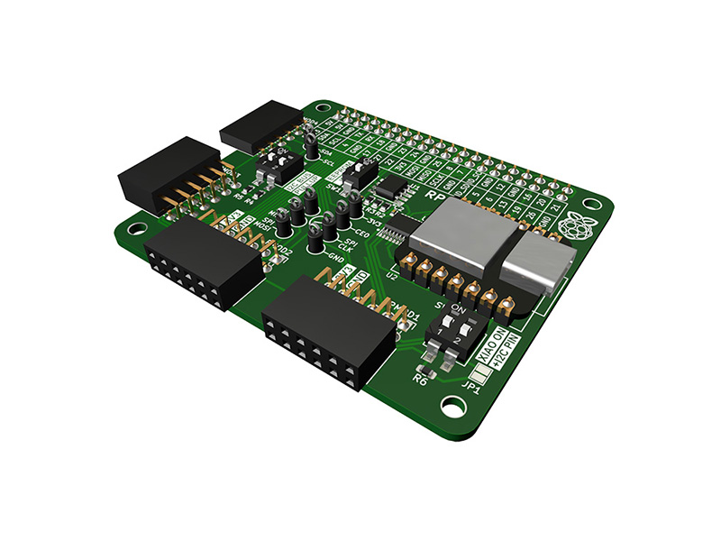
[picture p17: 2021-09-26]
images/pmod2rpi-top.jpg

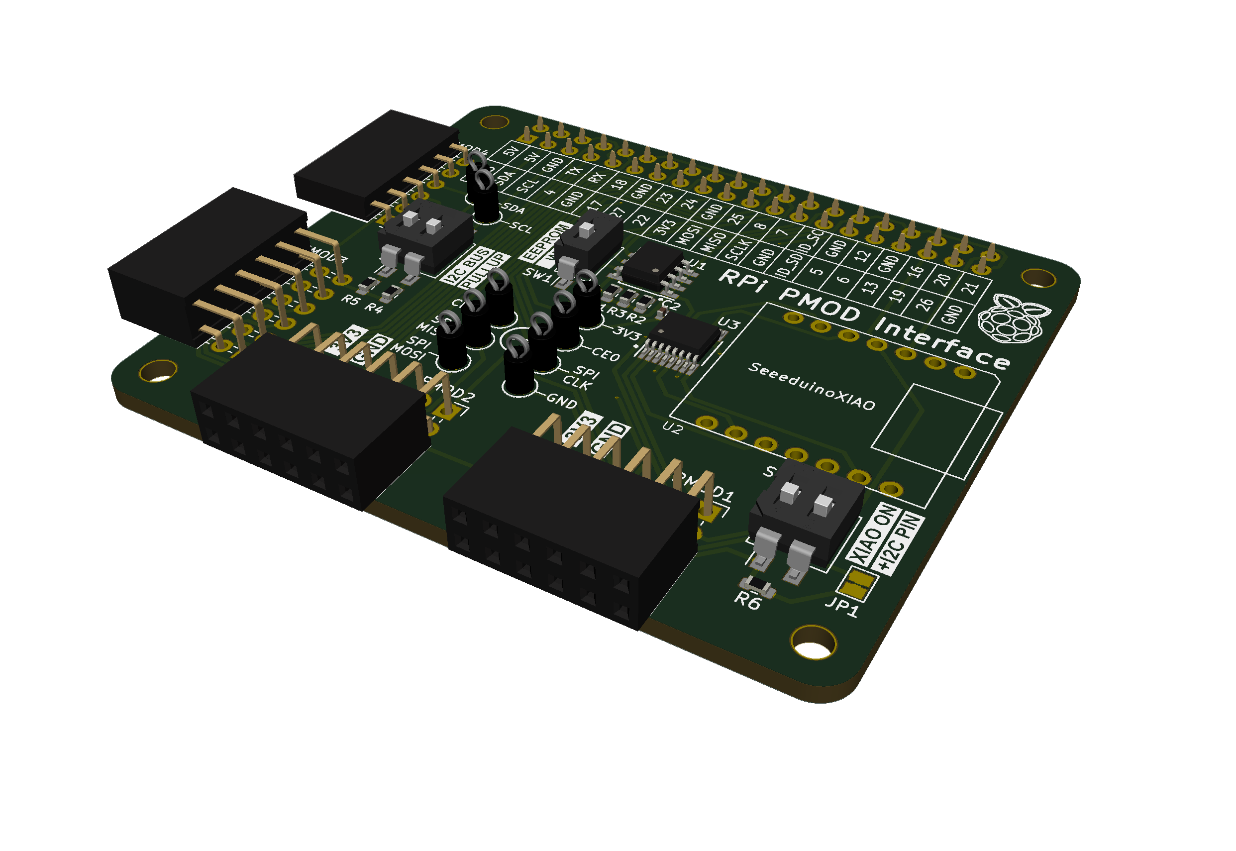
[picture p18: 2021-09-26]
images/pmod2rpi-angle-v1.png

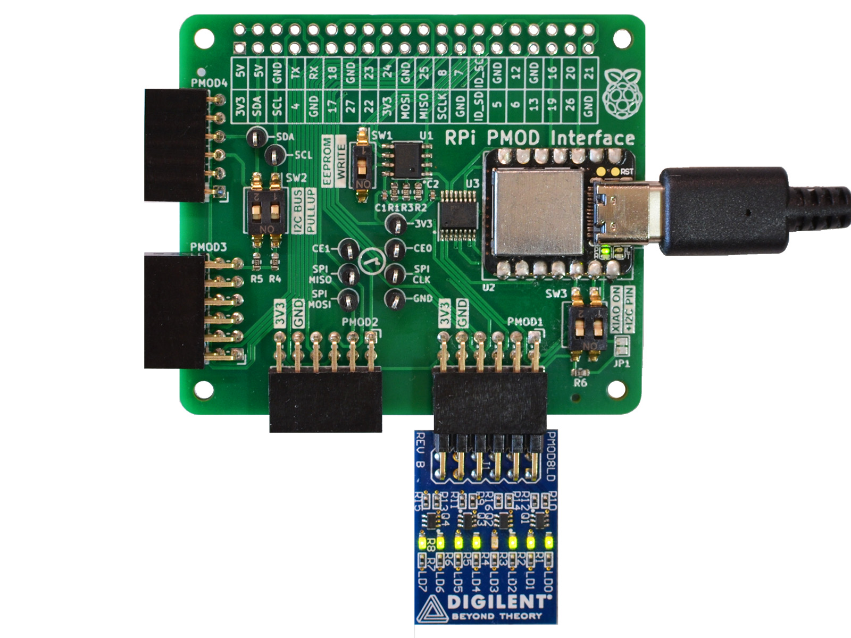
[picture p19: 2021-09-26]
images/pmod2rpi-xiao-8led-pmod-v10.jpg

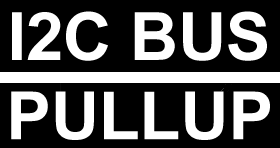
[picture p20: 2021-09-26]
images/i2c-pullup.bmp

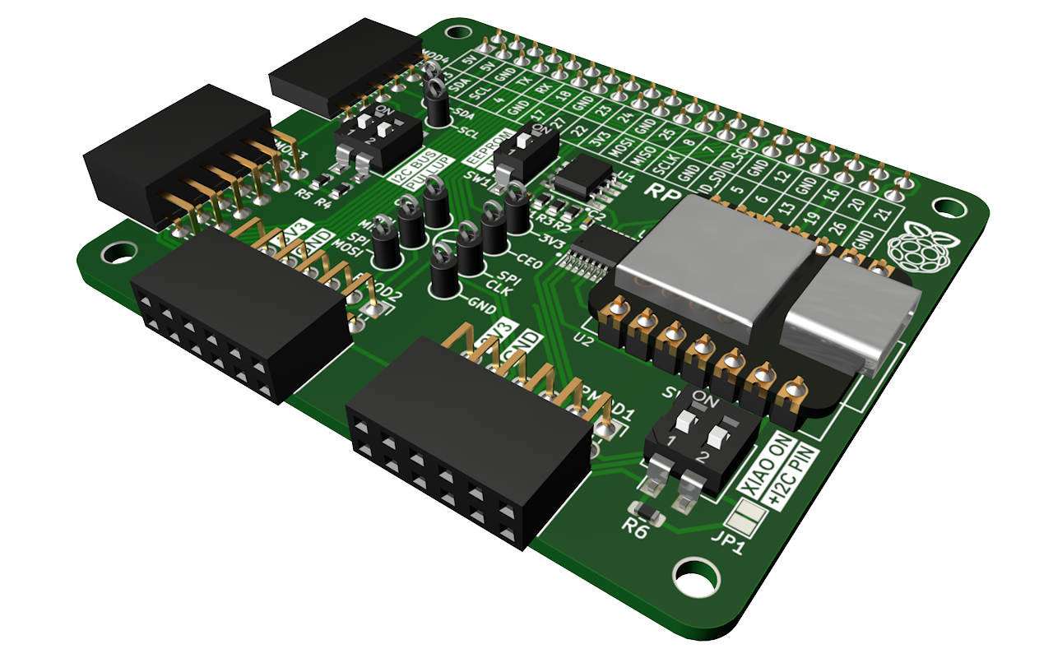
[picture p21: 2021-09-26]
images/pmod2rpi-render-v10.png

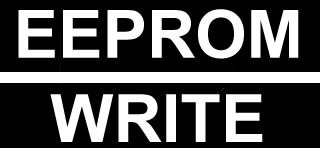
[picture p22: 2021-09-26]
images/eeprom.bmp

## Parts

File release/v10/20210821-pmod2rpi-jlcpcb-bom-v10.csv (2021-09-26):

Comment | Designator | Footprint | LCSC Part
CAT24C32WI-GT3 | U1 | SOIC-8_3.9x4.9mm_P1.27mm | C81193
0603WAF3901T5E | R2,R3 | Resistor_SMD:R_0603_1608Metric | C23018
PI5A100QEX | U3 | QSOP-16_3.9x4.9mm_P0.635mm | C526719
0603WAF1002T5E | R1,R6 | Resistor_SMD:R_0603_1608Metric | C25804
C0402C104K4RECAUTO | C1,C2 | Capacitor_SMD:C_0402_1005Metric | C696352
0603WAF4701T5E | R4,R5 | Resistor_SMD:R_0603_1608Metric | C23162
DSIC02LS-P | SW2,SW3 | SW_DIP_SPSTx02_W8.9mm_P2.54mm | C319042
DSIC01LS-P | SW1 | SW_DIP_SPSTx01_W8.9mm_P2.54mm | C600988

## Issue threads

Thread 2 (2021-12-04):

XIAO MCU footprint pin spacing

fm4dd, 2021-12-04:
When fitting the XIAO MCU, the footprint pin rail spacing is not 100% matching, but a fraction off. The original XIAO KiCAD footprint from [](https://wiki.seeedstudio.com/Seeeduino-XIAO/#resourses) was used. Need to check and update the footprint pin rail spacing, and also improve the pin hole shape to oval for easier direct (flat) mounting. The current footprint on the board is too tight.

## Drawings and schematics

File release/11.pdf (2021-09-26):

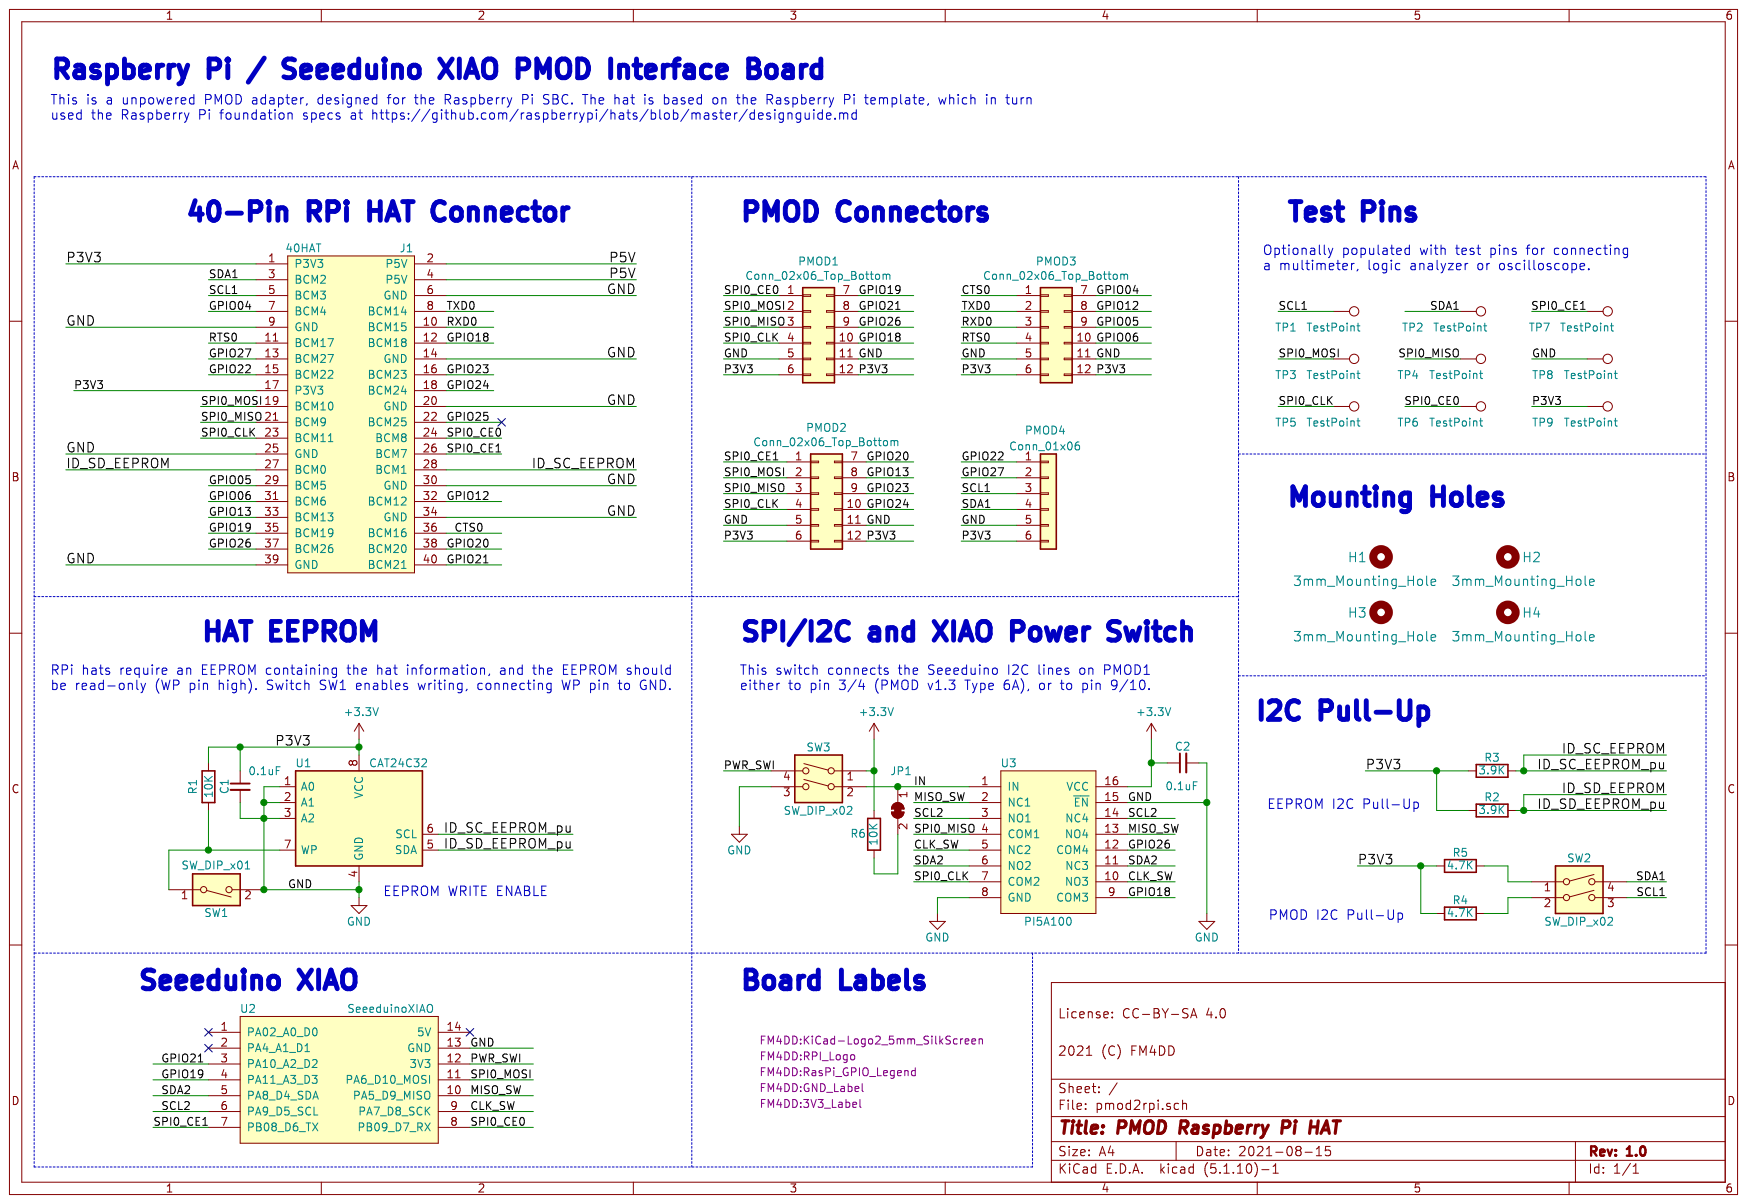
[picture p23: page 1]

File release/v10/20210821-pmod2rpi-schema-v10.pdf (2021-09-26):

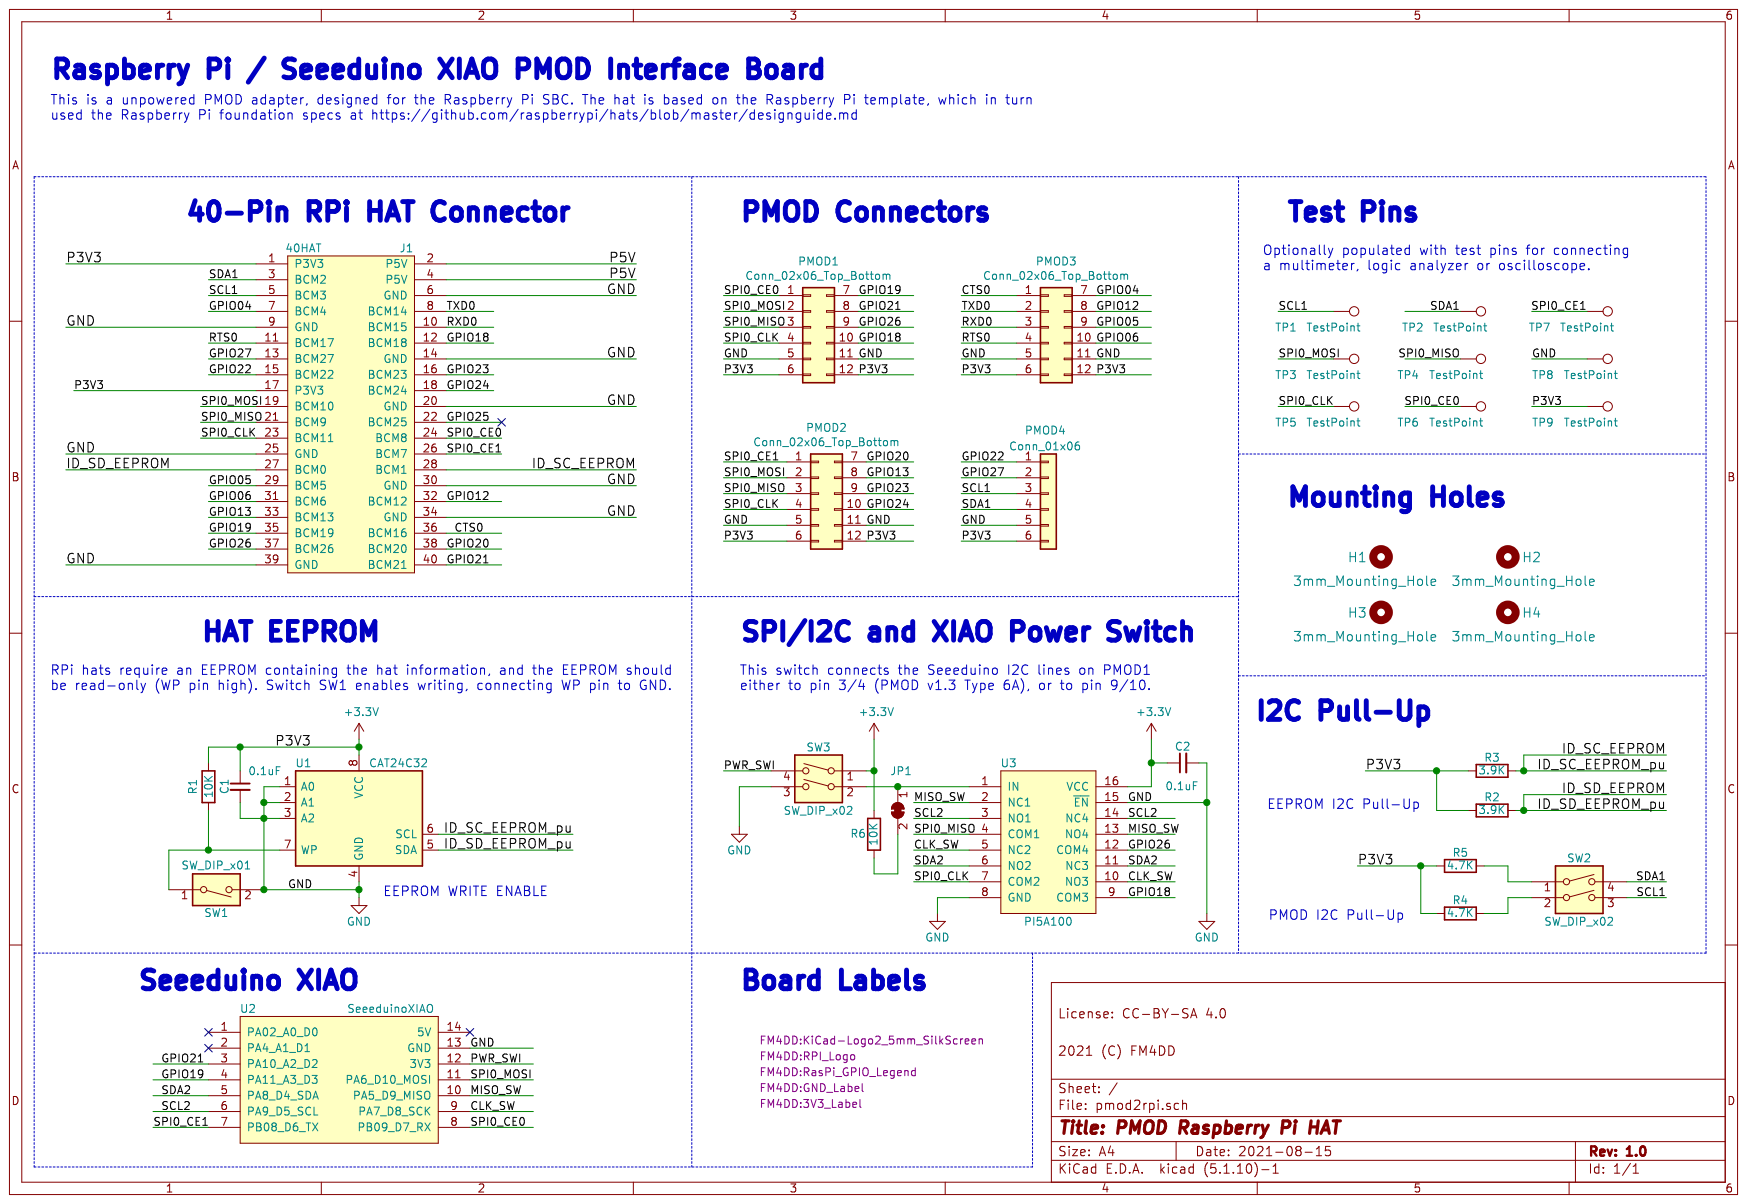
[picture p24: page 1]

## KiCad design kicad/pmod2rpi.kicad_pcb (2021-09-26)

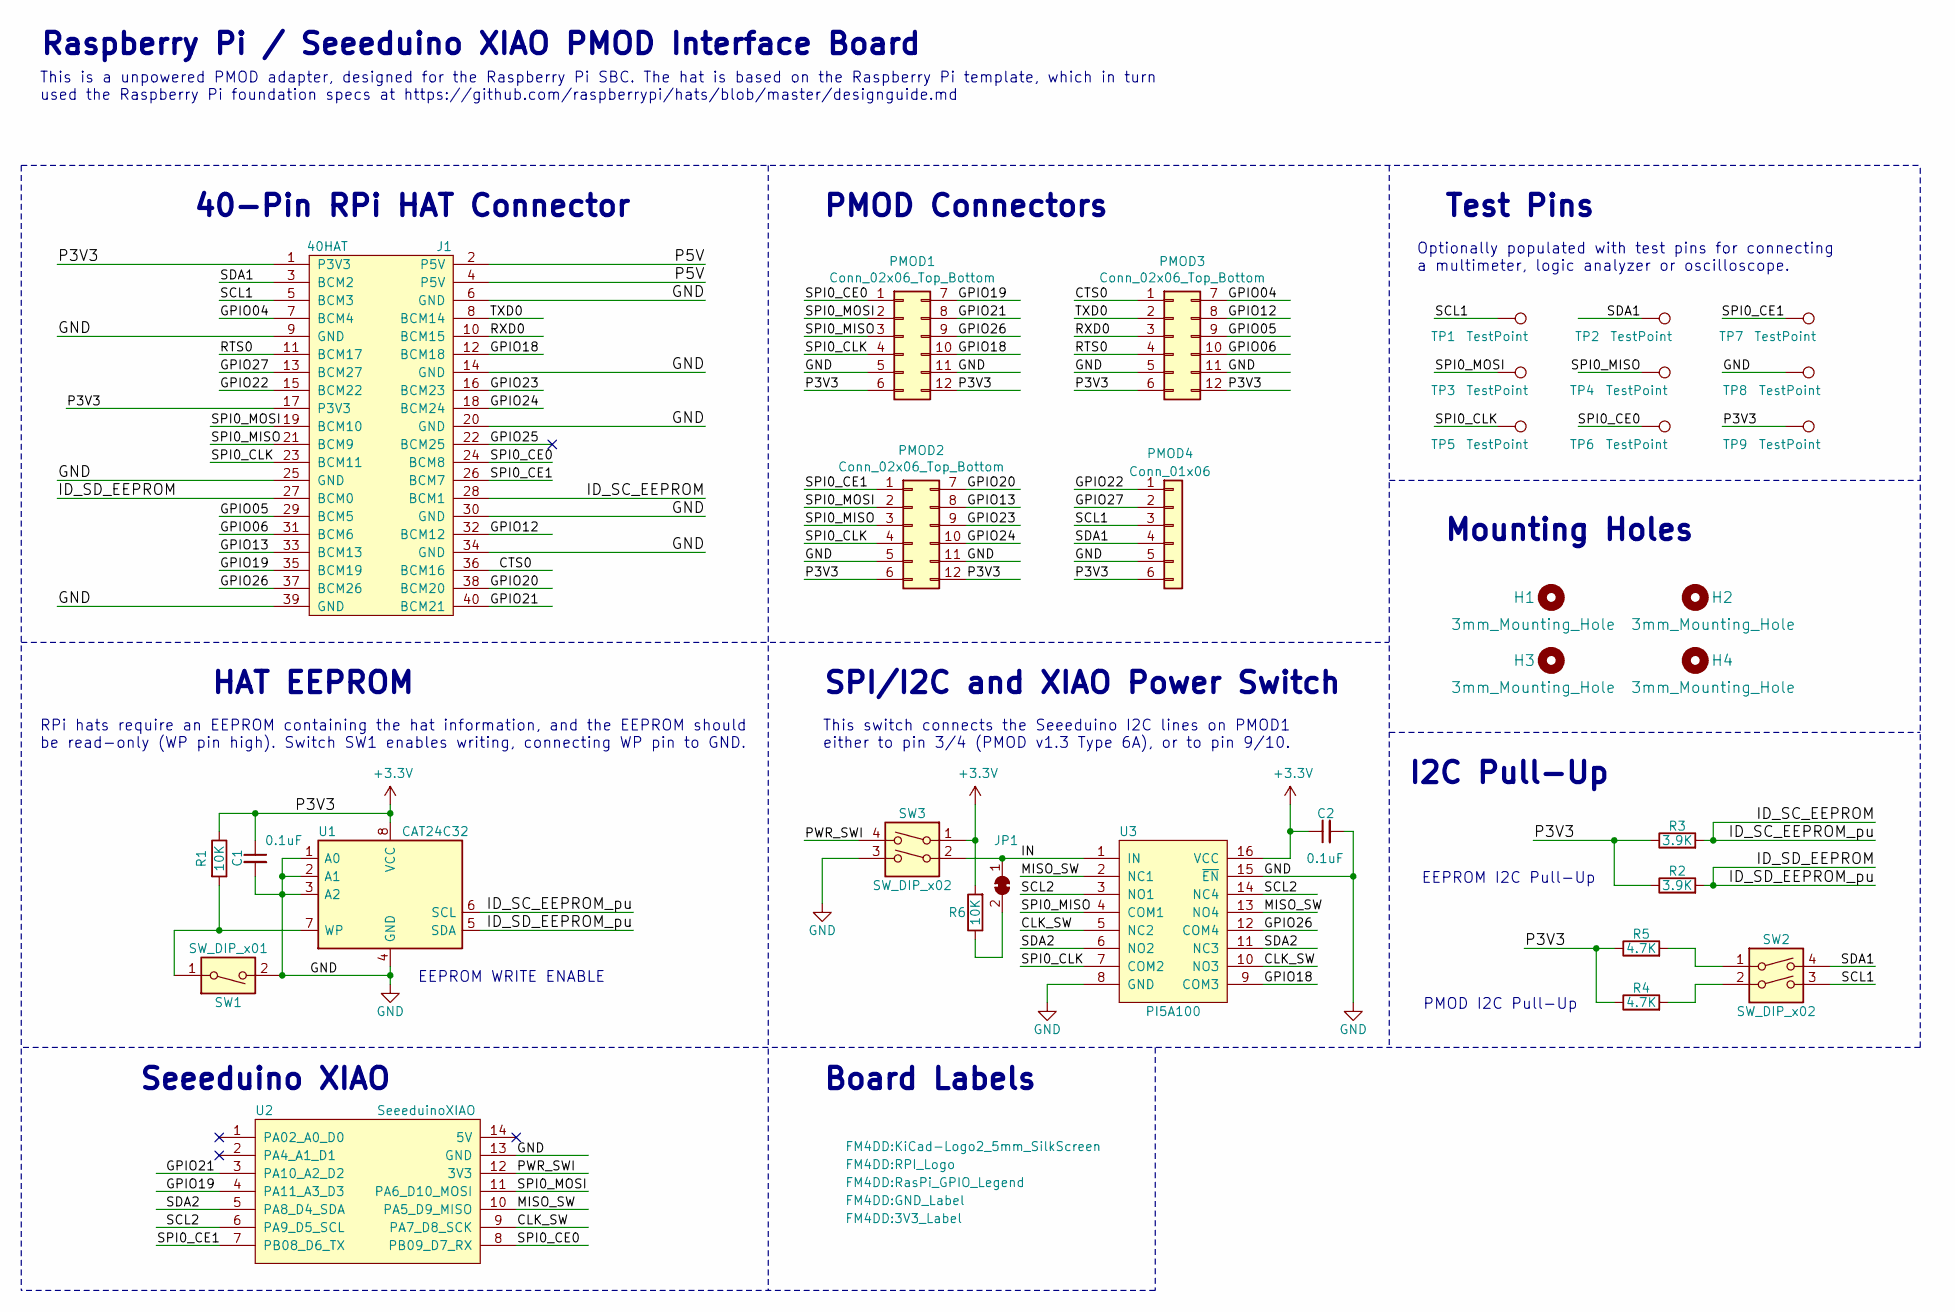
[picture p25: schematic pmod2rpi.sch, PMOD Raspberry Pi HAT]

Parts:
C1, C2: 0.1uF; C_0402_1005Metric
H1, H2, H3, H4: 3mm_Mounting_Hole; NPTH_3mm_ID
J1: 40HAT; PinSocket_2x20_P2.54mm_Vertical
JP1: SolderJumper_2_Bridged; SolderJumper-2_P1.3mm_Bridged_Pad1.0x1.5mm
L1: Logo_KiCad_5mm; KiCad-Logo2_5mm_SilkScreen
L2: Logo_RPI; RPI_Logo
L3: Pinout_RPI_GPIO; RasPi_GPIO_Legend
L4: GND_Label
L5: 3V3_Label
PMOD1, PMOD2, PMOD3: Conn_02x06_Top_Bottom; PMODPinSocket_2x06_P2.54mm_Horizontal
PMOD4: Conn_01x06; PMODPinSocket_1x06_P2.54mm_Horizontal
R1, R6: 10K; R_0603_1608Metric
R2, R3: 3.9K; R_0603_1608Metric
R4, R5: 4.7K; R_0603_1608Metric
SW1: SW_DIP_x01; SW_DIP_SPSTx01_XKB_DSIC01LS
SW2, SW3: SW_DIP_x02; SW_DIP_SPSTx02_XKB_DSIC02LS
TP1, TP2, TP3, TP4, TP5, TP6, TP7, TP8, TP9: TestPoint; TestPoint_Keystone_5000-5004_Miniature
U1: CAT24C32; SOIC-8_3.9x4.9mm_P1.27mm
U2: SeeeduinoXIAO; SeeeduinoXIAO-14P-2.54-21X17.8MM
U3: PI5A100; QSOP-16_3.9x4.9mm_P0.635mm

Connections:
+3V3: C1.1, C2.1, J1.1 (P3V3), J1.17 (P3V3), PMOD1.6, PMOD1.12, PMOD2.6, PMOD2.12, PMOD3.6, PMOD3.12, PMOD4.6, R1.1, R2.1, R3.1, R4.1, R5.1, R6.2, SW3.1, TP9.1, U1.8 (VCC), U3.16 (VCC)
/CLK_SW: U2.9 (PA7_D8_SCK), U3.5 (NC2), U3.10 (NO3)
/CTS0: J1.36 (BCM16), PMOD3.1
/GPIO04: J1.7 (BCM4), PMOD3.7
/GPIO05: J1.29 (BCM5), PMOD3.9
/GPIO06: J1.31 (BCM6), PMOD3.10
/GPIO12: J1.32 (BCM12), PMOD3.8
/GPIO13: J1.33 (BCM13), PMOD2.8
/GPIO18: J1.12 (BCM18), PMOD1.10, U3.9 (COM3)
/GPIO19: J1.35 (BCM19), PMOD1.7, U2.4 (PA11_A3_D3)
/GPIO20: J1.38 (BCM20), PMOD2.7
/GPIO21: J1.40 (BCM21), PMOD1.8, U2.3 (PA10_A2_D2)
/GPIO22: J1.15 (BCM22), PMOD4.1
/GPIO23: J1.16 (BCM23), PMOD2.9
/GPIO24: J1.18 (BCM24), PMOD2.10
/GPIO26: J1.37 (BCM26), PMOD1.9, U3.12 (COM4)
/GPIO27: J1.13 (BCM27), PMOD4.2
/ID_SC_EEPROM: J1.28 (BCM1), R3.2, U1.6 (SCL)
/ID_SD_EEPROM: J1.27 (BCM0), R2.2, U1.5 (SDA)
/IN: JP1.1 (A), SW3.2, U3.1 (IN)
/MISO_SW: U2.10 (PA5_D9_MISO), U3.2 (NC1), U3.13 (NO4)
/P5V: J1.2 (P5V), J1.4 (P5V)
/PWR_SWI: SW3.4, U2.12 (3V3)
/RTS0: J1.11 (BCM17), PMOD3.4
/RXD0: J1.10 (BCM15), PMOD3.3
/SCL1: J1.5 (BCM3), PMOD4.3, SW2.3, TP1.1
/SCL2: U2.6 (PA9_D5_SCL), U3.3 (NO1), U3.14 (NC4)
/SDA1: J1.3 (BCM2), PMOD4.4, SW2.4, TP2.1
/SDA2: U2.5 (PA8_D4_SDA), U3.6 (NO2), U3.11 (NC3)
/SPI0_CE0: J1.24 (BCM8), PMOD1.1, TP6.1, U2.8 (PB09_D7_RX)
/SPI0_CE1: J1.26 (BCM7), PMOD2.1, TP7.1, U2.7 (PB08_D6_TX)
/SPI0_CLK: J1.23 (BCM11), PMOD1.4, PMOD2.4, TP5.1, U3.7 (COM2)
/SPI0_MISO: J1.21 (BCM9), PMOD1.3, PMOD2.3, TP4.1, U3.4 (COM1)
/SPI0_MOSI: J1.19 (BCM10), PMOD1.2, PMOD2.2, TP3.1, U2.11 (PA6_D10_MOSI)
/TXD0: J1.8 (BCM14), PMOD3.2
GND: C1.2, C2.2, J1.6 (GND), J1.9 (GND), J1.14 (GND), J1.20 (GND), J1.25 (GND), J1.30 (GND), J1.34 (GND), J1.39 (GND), PMOD1.5, PMOD1.11, PMOD2.5, PMOD2.11, PMOD3.5, PMOD3.11, PMOD4.5, SW1.2, SW3.3, TP8.1, U1.1 (A0), U1.2 (A1), U1.3 (A2), U1.4 (GND), U2.13 (GND), U3.8 (GND), U3.15 (~EN)
unnamed: JP1.2 (B), R6.1
unnamed: R1.2, SW1.1, U1.7 (WP)
unnamed: R4.2, SW2.2
unnamed: R5.2, SW2.1

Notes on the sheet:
EEPROM WRITE ENABLE
I2C Pull-Up
HAT EEPROM
Mounting Holes
40-Pin RPi HAT Connector
RPi hats require an EEPROM containing the hat information, and the EEPROM should be read-only (WP pin high). Switch SW1 enables writing, connecting WP pin to GND.
This is a unpowered PMOD adapter, designed for the Raspberry Pi SBC. The hat is based on the Raspberry Pi template, which in turn used the Raspberry Pi foundation specs at https://github.com/raspberrypi/hats/blob/master/designguide.md
PMOD Connectors
EEPROM I2C Pull-Up
Optionally populated with test pins for connecting a multimeter, logic analyzer or oscilloscope.
Test Pins
Board Labels
Raspberry Pi / Seeeduino XIAO PMOD Interface Board
SPI/I2C and XIAO Power Switch
This switch connects the Seeeduino I2C lines on PMOD1 either to pin 3/4 (PMOD v1.3 Type 6A), or to pin 9/10.
Seeeduino XIAO
PMOD I2C Pull-Up

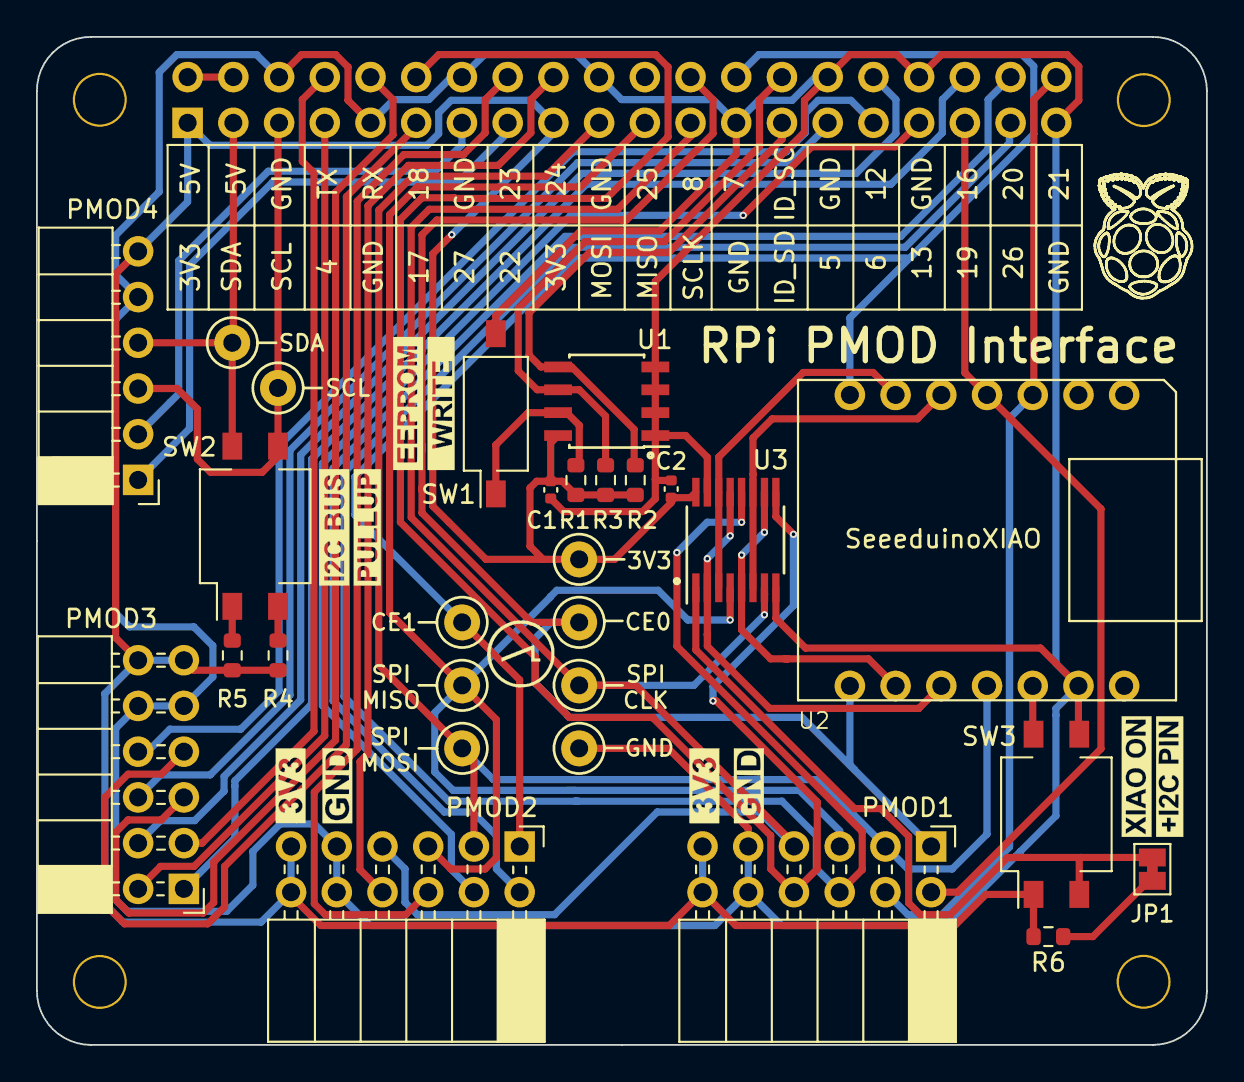
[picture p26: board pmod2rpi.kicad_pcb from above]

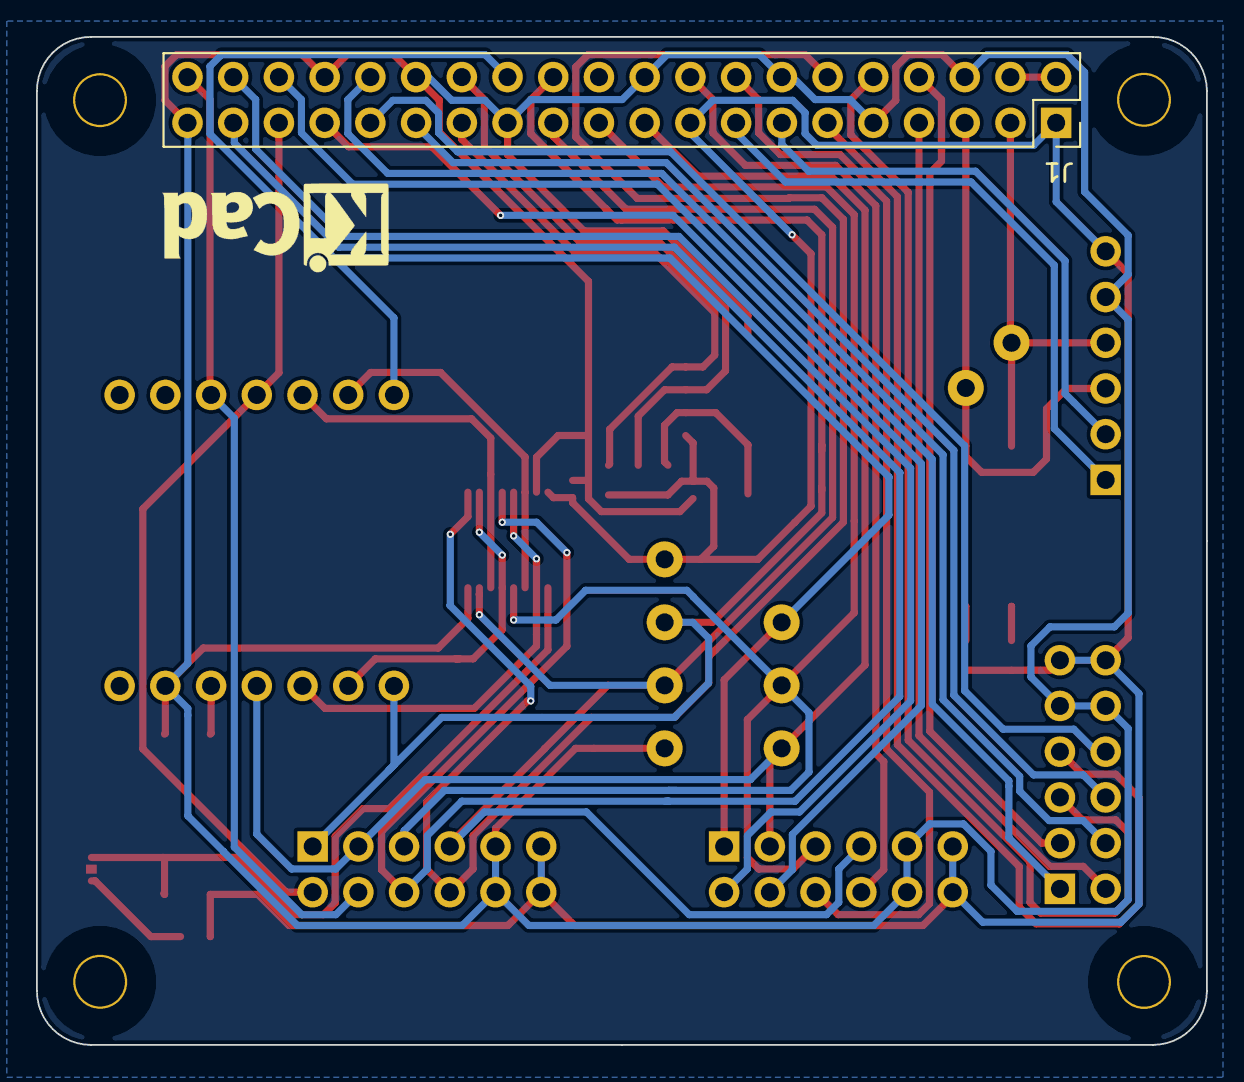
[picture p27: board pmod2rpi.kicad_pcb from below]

Board: 2 copper layers, 65.0 x 56.0 mm, 41 parts (2 on the bottom side), 40 nets.

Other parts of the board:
L4#2: GND_Label
L5#2: 3V3_Label
SN1: JLCPCB_serial_location; JLCPCB_Order_Number_Placeholder

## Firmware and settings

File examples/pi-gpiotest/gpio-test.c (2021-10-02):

/* ------------------------------------------------------------ *
 * file:        gpio-test.c                                     *
 * purpose:     digital pin control program for PMOD2RPI board  *
 *              sets PMOD1-connected RPi GPIO pins as output,   *
 *              and blinks 20 times on pin 0 and 1. This prog   *
 *              is best used with an Digilent's PMOD8LD module. *
 *                                                              *
 * requires:    GPIOD library                                   *
 *              e.g. sudo apt install libi2c-dev libgpiod-dev   *
 *                                                              *
 * example:     ./gpio-test                                     *
 *                                                              *
 * author:      09/09/2021 Frank4DD                             *
 * ------------------------------------------------------------ */
#include <gpiod.h>
#include <stdio.h>
#include <unistd.h>

#define PMOD     "pmod1"
#define CHIPNAME "gpiochip0"

// Global variables
struct gpiod_chip *chip;

void release_line(struct gpiod_line *line) {
   int ret = gpiod_line_set_value(line, 0);
   gpiod_line_release(line);
}

void get_pmod_lines(unsigned int pins[], struct gpiod_line *lines[]) {
   for(int i=0; i<8; i++) {
      lines[i] = gpiod_chip_get_line(chip, pins[i]);
      if(!lines[i]) {
         perror("Get line failed\n");
         gpiod_chip_close(chip);
         exit(127);
      }
   }
}

void set_pmod_lines_output(struct gpiod_line *lines[], int level){
   int ret = 0;
   for(int i=0; i<8; i++) {
      gpiod_line_request_output(lines[i], PMOD, level);
   }
   if(ret != 0) {
   // error handling
   }
}

int main(int argc, char **argv) {
   // -----------------------------------------------------------------
   // Enable the Raspberry Pi GPIO interface chip to control the pins
   // -----------------------------------------------------------------
   chip = gpiod_chip_open_by_name(CHIPNAME);
   if (!chip) {
      perror("Open chip failed\n");
      return 0;
   }

   // -----------------------------------------------------------------
   // PMOD1 Raspberry Pi GPIO + connector pin assignment array pmod_pin
   // Note: PMOD2 pins 2..4 mirror PMOD1 to provide 2x SPI device ports
   // -----------------------------------------------------------------
   unsigned int pmod_pins[8];
   pmod_pins[0] = 8;   // GPIO #08, Connector Pin 24 = LD0
   pmod_pins[1] = 10;  // GPIO #10, Connector Pin 19 = LD1
   pmod_pins[2] = 9;   // GPIO #09, Connector Pin 21 = LD2
   pmod_pins[3] = 11;  // GPIO #11, Connector Pin 23 = LD3
   pmod_pins[4] = 19;  // GPIO #19, Connector Pin 35 = LD4
   pmod_pins[5] = 21;  // GPIO #21, Connector Pin 40 = LD5
   pmod_pins[6] = 26;  // GPIO #26, Connector Pin 37 = LD6
   pmod_pins[7] = 18;  // GPIO #18, Connector Pin 12 = LD7

   // -----------------------------------------------------------------
   // For the given list of pin #, obtain the line objects for each
   // -----------------------------------------------------------------
   struct gpiod_line *pmod_lines[8];
   get_pmod_lines(pmod_pins, pmod_lines);

   // -----------------------------------------------------------------
   // Set lines as output, with initial logic level of '0'
   // -----------------------------------------------------------------
   set_pmod_lines_output(pmod_lines, 0);

   unsigned int val;
   int ret;
   // -----------------------------------------------------------------
   // Blink 20 times on pins 0 and 1, alternating '0' and '1' at 1Hz 
   // -----------------------------------------------------------------
   val = 0;
   for (int i = 20; i > 0; i--) {
      ret = gpiod_line_set_value(pmod_lines[0], val);
      if (ret < 0) {
         perror("Set line output failed\n");
                        release_line(pmod_lines[0]);
      }
      ret = gpiod_line_set_value(pmod_lines[1], !val);
      if (ret < 0) {
         perror("Set line output failed\n");
                        release_line(pmod_lines[1]);
      }
      printf("%d Output %u on line1 #%u\n",i, val, pmod_pins[0]);
      printf("%d Output %u on line2 #%u\n",i, !val, pmod_pins[1]);
      usleep(1000000);
      val = !val;
   }

   return 0;
}

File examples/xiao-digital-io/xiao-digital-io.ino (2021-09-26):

// xiao-digital-io
//
// A modified LED blink program that tests
// the Digilent 8-Led PMOD 8LD connected to
// a PMOD2RPI PMOD interface board's PMOD1.
//
// PMOD1 XIAO pin assignment:
// -----------------------------------------
// pmod1-1 = XIAO gpio D7  / pin J4-1 = LD0
// pmod1-2 = XIAO gpio D10 / pin J4-4 = LD1
// pmod1-3 = XIAO gpio D9  / pin J4-3 = LD2
// pmod1-4 = XIAO gpio D8  / pin J4-2 = LD3
// pmod1-5 = XIAO gpio D3  / pin J2-4 = LD4
// pmod1-6 = XIAO gpio D2  / pin J2-3 = LD5
// pmod1-7 = XIAO gpio D5  / pin J2-6 = LD6
// pmod1-8 = XIAO gpio D4  / pin J2-5 = LD7
// -----------------------------------------
// Note:
// PMOD2RPI SW3 flips pmod1-3/4 with pmod1-7/8 

void setup() {
  // initialize PMOD1 digital pins output.
  pinMode(2, OUTPUT);
  pinMode(3, OUTPUT);
  pinMode(4, OUTPUT);
  pinMode(5, OUTPUT);
  pinMode(6, OUTPUT);
  pinMode(7, OUTPUT);
  pinMode(8, OUTPUT);
  pinMode(9, OUTPUT);
  pinMode(10, OUTPUT);
  // turn on all 8 LED on Digilent 8LD
  // Assignment with PMOD2RPI SW3-1 ON
  digitalWrite( 7, HIGH); // LD0
  digitalWrite(10, HIGH); // LD1
  digitalWrite( 9, HIGH); // LD2 (LD6)
  digitalWrite( 8, HIGH); // LD3 (LD7)
  digitalWrite( 3, HIGH); // LD4
  digitalWrite( 2, HIGH); // LD5
  digitalWrite( 5, HIGH); // LD6 (LD2)
  digitalWrite( 4, HIGH); // LD7 (LD3)
}

void loop() {
  digitalWrite(8, HIGH);  // turn LED LD2 on
  digitalWrite(9, LOW);   // turn LED LD3 off
  delay(500);             // wait half a second
  digitalWrite(8, LOW);   // turn LED LD2 off
  digitalWrite(9, HIGH);  // turn LED LD3 on
  delay(500);             // wait half a second
}

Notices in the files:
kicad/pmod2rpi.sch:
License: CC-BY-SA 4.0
